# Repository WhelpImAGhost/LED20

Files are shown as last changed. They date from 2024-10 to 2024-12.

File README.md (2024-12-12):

# ECE 411 - LED20
### Team 1
- Brad Glaubitz
- Chris Kane-Pardy
- Caleb Monti
- Henry Sanders

## Project Overview
The purpose of the LED20 project is to add a fun and interesting spin to modern D20s (20 sided dice) for various tabletop games. Rather than a standard D20 which simply shows which face is rolled, the LED20 will illuminate the face that was rolled, and play special sound effects when a 1 or 20 is rolled. This added flare will spice up any tabletop game, and can be customized to your liking! [^1]

## Important Files and Folders Directory
This repository holds all design and development documents that were either assigned or created out of necessity throughout this project, including the Product Design Specification and Bill of Materials. However, for someone interested in creating their own copy of the LED20, some of these files and folders are not required. So, we have compiled a list of the files and folders that are necessary for understanding and replicating this project

### Links to files and folders
- [Full Project Description](./Project%20Info%20and%20Requirements/Project%20Information%20and%20Requirements.pdf): A more in-depth explanation of the project details and required features
- [Functional Decomposition](./Functional%20Decomposition/): Other high-detail files which explain the inner hardware and software functions and connections
- [Bill of Materials](./BOMs/Bill%20of%20Materials%20v4.xlsx): The list of required components to recreate the circuit
- [3D Model Files](./CAD/3D%20Model/): Iterations of development for the 3D printed D20 enclosure and charging base
- [PCB Development Files](./CAD/Schematics%20and%20PCB%20Layouts/): Required files for modifying or fabricating the carrier circuit board
- [Code](./LED20_Code/): Most recent iteration of the code, developed using ESP-IDF for the ESP32-C6

[^1]: Customization must take place before the die is sealed, as there is not a current way to interface with the processor after the enclosure is fully sealed. Please make any changes to LED Color, 1 & 20 Tones, and Sleep States before sealing your die.

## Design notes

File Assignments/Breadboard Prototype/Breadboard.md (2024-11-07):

# Breadboard Prototype Update

Our breadboard prototype is coming along nicely. All features that we currently have in hand are functional and controllable, including:

- Controlling the ESP32-C6
- Configuring, writing to, and reading from the LSM6D032 Accelerometer and Gyroscope sensor
- Enabling and controlling interrupts from the LSM6D032 sensor
- Controlling a fixed number of NeoPixel or WS2811 LEDs with fixed timing

Below is a close-up image of our current breadboard prototype
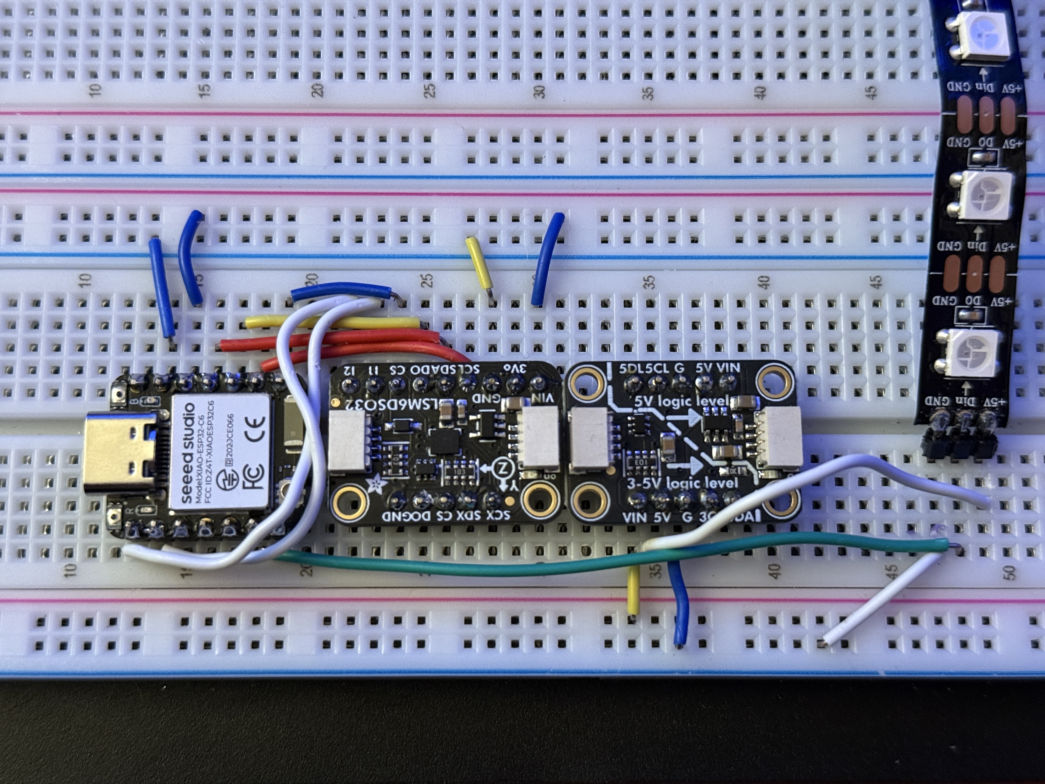
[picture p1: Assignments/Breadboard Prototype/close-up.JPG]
Breadboard Prototype close-up


We also have a couple images representing our data transfers between the ESP32-C6 and the LSM6D032 sensor over a 4-wire SPI interface:

Example SPI transfer using a logic analyzer:
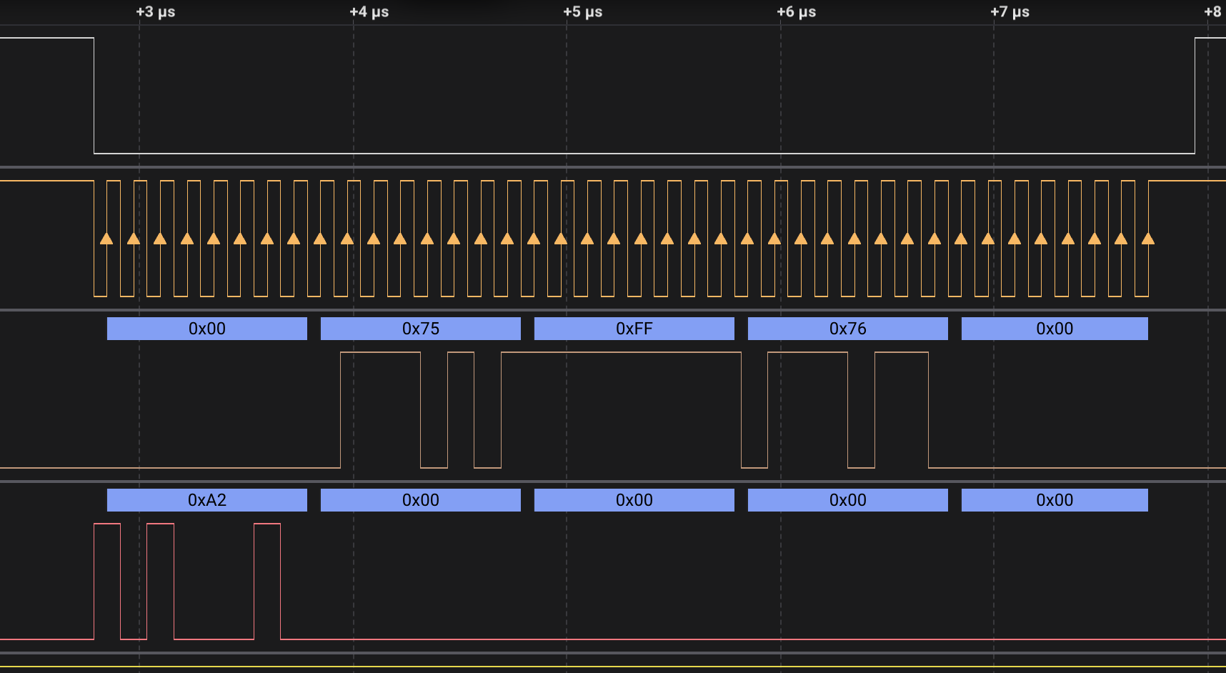
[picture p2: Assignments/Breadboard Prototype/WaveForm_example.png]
Logic analyzer example


In this image, you can clearly see the interaction and data that was transferred between the two devices. In this case, the ESP32-C6 was reading from four registers starting at register 0xA2 and receiving four data packets from the LSM6D032.

Next, an image showing our data after some computation into a human-readable format:  
Example data in human-readable format  
In this image, the hex data from the LSM6D032 is converted to a physical number we can use to determine information such as when the die stops moving and what orientation it is in when it stops moving.

Finally, the lightshow!
[Click here for lightshow video](https://youtu.be/P9tXDaBaYNc), or alternatively see the "animated-lights.mov" file.

With all of our code functioning individually, we are very close to having a fully functional project on the code side.

### Note
One of our project requirements is to make sound when a certain roll is detected. Currently the Piezo to do such sounds is not installed on the ESP32-C6, but creating a PWM signal from the ESP32-C6 to drive a passive buzzer is beyond trivial. The main focus on the code to this point has been to develop the more complex and intricate code and components to get them to function in unison.

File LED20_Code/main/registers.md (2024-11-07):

# Registers and values required

### Notes on sensor setup
- Disable I2C in CTRL4_C
- Set Accelerometer operation mode in register CTRL1_XL (0x10)
- Set Gyroscope operation mode in register CTRL2_G (0x11)
- Software Reset, Register Increment, and interrupt activation level set in CTRL3_C (0x12)
- Disable I3C using CTRL9_XL

### Notes on Interrrupt setup
- Interrupt Setup is configured by switching to Embedded Function control mode by writing 0x1 to the FUNC_CFG_ACCESS (0x1) register
- Enable "Significant Motion Detection" in register EMB_FUNC_EN_A (04h)
- Route SMD interrupt to INT1 and Inactivity to INT2

- Interrupt status cleared by reading interrupt register
    - For SMD interrupt, read EMB_FUNC_STATUS_MAINPAGE (0x35) register
- TAP has inactivity sensor. Activity interrupt can be used to wake processor from sleep

### Notes on Data Acquisition
- Data is back into two bytes, stored in Two's Complement format
- L register is bits 7-0, H register is 15-8
- Accelerometer data registers:
    - OUTX_L_A (0x28) and OUTX_H_A (0x29) - X axis linear acceleration
    - OUTY_L_A (0x2A) and OUTY_H_A (0x2B) - Y axis linear acceleration
    - OUTZ_L_A (0x2C) and OUTZ_H_A (0x2D) - Z axis linear acceleration
- Gyroscope data registers:
    - OUTX_L_G (0x22) and OUTX_H_G (0x23) - X axis angular rate value
    - OUTY_L_G (0x24) and OUTY_H_G (0x25) - Y axis angular rate value
    - OUTZ_L_G (0x26) and OUTZ_H_G (0x27) - Z axis angular rate value
- Temperature data registers:
    - OUT_TEMP_LOW (0x20) and OUT_TEMP_HIGH (0x21) - Temperature output register

# Cheatsheet

# A first-level heading
## A second-level heading
### A third-level heading

Style	Syntax	Keyboard shortcut	Example	Output
Bold	** ** or __ __	Command+B (Mac) or Ctrl+B (Windows/Linux)	**This is bold text**	This is bold text
Italic	* * or _ _     	Command+I (Mac) or Ctrl+I (Windows/Linux)	_This text is italicized_	This text is italicized
Strikethrough	~~ ~~	None	~~This was mistaken text~~	This was mistaken text
Bold and nested italic	** ** and _ _	None	**This text is _extremely_ important**	This text is extremely important
All bold and italic	*** ***	None	***All this text is important***	All this text is important
Subscript	<sub> </sub>	None	This is a <sub>subscript</sub> text	This is a subscript text
Superscript	<sup> </sup>	None	This is a <sup>superscript</sup> text	This is a superscript text
Underline	<ins> </ins>	None	This is an <ins>underlined</ins> text	This text is underlined

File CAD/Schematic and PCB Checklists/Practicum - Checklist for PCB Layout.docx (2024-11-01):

# Checklist for PCB Layouts

Andrew Greenberg - http://github.com/andrewgreenberg

v2021-10-28

Pre-layout Checklist

- Create board from schematic.
- Set your grid to something reasonable (e.g., 0.1 mm grid, or 0.01 inch grid).
- Start with your best guess for an outline of your board.

Lay out strategies

- Place all components that must be in a certain spot (e.g., connectors and mounting holes)
- Move components that are in a “schematic block” together, then optimally rotate and place components to reduce crossed airwires, then route.
- Optimally rotate and place grouped components to minimize airwires, then route.
- Flood ground planes, stitching them together early and often.
- Route very high speed lines (e.g., RF, clocks, USB 2.0), minimizing length
- Route power lines, minimizing impedance.
- Route busses.
- Route everything else.

Layout checklist

- Is there enough physical space around components for assembly?
- Are your test points in easily accessible places?
- Are there any hidden traces that you can't probe?

Best Practices

- Are all of the small bypass caps right next to the power and ground leads of the ICs?
- Are the power lines as wide as reasonably possible?
- Did you use either larger drills for power lines, or multiple small vias for power lines?
- Are there ground planes on both sides? (Make sure your polygons have an isolate of > design rule; e.g., with a design rule of 6 mils, make the isolate 10 mils).
- Are your ground planes stitched together with vias?
- Is your board as small as possible?
- Run your DRC early and often

Post-layout checklist

- Modify reference designators to be as small as possible, and move them around to be readable/useful. Avoid placing text on pads and vias.
- Verify that at least the organization name, the name of the board, and version number are on the silkscreen.

Final checkout

- Print out 1:1 PCB and lay components on printout to double check packages.
- Run DRC; there should be no errors.
- Make sure all components in stock, or that components you specified are in stock before firing off board.

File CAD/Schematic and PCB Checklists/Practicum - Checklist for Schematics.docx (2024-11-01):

# Checklist for Schematics

Andrew Greenberg - http://github.com/andrewgreenberg

v2021-10-29

- Visual Design
  - Power supplies use supply symbols, not wires
  - Positive supplies point up, and negative supplies/ground point down
  - Optional: Groups of nets above about ≥ 4 nets collected into buses
  - Component symbols are symbols, not the physical package's order and arrangement
  - All nets descriptively named
  - Net “stubs” (nets visually connected to only one pin) use an “off-sheet” type of label
  - Blocks in your schematic clearly labeled
  - There's a frame around the schematic
  - It's clear where your power is coming from
  - It's clear what your power input requirements are
  - Data flow (inputs, outputs) are clear and labeled
- Part values
  - Special case capacitors marked with power and tolerance
  - Capacitors have the appropriate voltage
  - Power dissipation checked in all of your resistors
  - Special case resistors marked with power and tolerance
  - Check that your specialized parts are in stock at a distributor
- Electrical Rule checks
  - All of your components have values (including “NP” for "No Place")
  - All inputs have the correct voltage levels
  - All outputs have the correct load impedance
  - MOSFETs oriented correctly, including the body diode
  - No unapproved errors OR warnings in the ERC
  - Double check your approved errors, looking for anomalies and possible errors.
- Best Practices
  - Your schematic is peer reviewed by at least one person not involved in the design.
  - Small, low ESR (e.g., ceramic) bypass capacitors on ALL IC supplies
  - Large bypass (e.g., electrolytic) capacitors on your board at the power connector and regulator IC.
  - Design for Test
    - Place test points on critical signals
    - Add debugging hardware (e.g., test switches, LEDs, scope probe points, etc)
  - Design for Fail
    - Group components in separable modular blocks, use zero ohm resistors as jumpers
  - Design for Manufacturing
    - Place programming connectors and DOUBLE CHECK their pinouts
    - Double check your part numbers and the actual package names and dimensions.

Please comment (https://docs.google.com/document/d/1tzhaX46BbXsmi481ztf1Z_laDdik5dUJDNGWxPAsZL4/edit?usp=sharing) on this checklist!

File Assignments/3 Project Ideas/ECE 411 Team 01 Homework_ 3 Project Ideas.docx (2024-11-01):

ECE 411 Homework: 3 Project Ideas

Idea 1: ASL Glove (cont. from ECE 212)

- Brief description: Device that translates ASL to English or other languages in real time to text and/or speech. Optimized for better processing and speed
- List of sensors: Gyroscope, Accelerometer, Resistive flex sensor
- List of controllers: ESP32 or Arduino Nano
- List of actuators: Phone App

Idea 2: Tile Rhythm Game

- Brief description: Similar to BopIt™, but a tiled “drum pad” with X number of pads that light up and play a sound in a particular order which the user then has to repeat back.
- List of sensors: Capacitive or Piezo force sensors
- List of controllers: ESP32, RPi Pico, or Arduino Nano
- List of actuators: LEDs, sound

Idea 3: LED20

- Brief description: D20 that lights up the rolled number, may play sound upon rolling a 1 or 20. May detonate upon rolling 2 consecutive 1s
- List of sensors: Gyroscope, Accelerometer,
- List of controllers: ESP32-S3 or RP2040
- List of actuators: LEDs, sound

Why we chose LED20: The idea seems reasonable to achieve within the timeframe of the class. Additionally, it checks all the project requirement boxes.

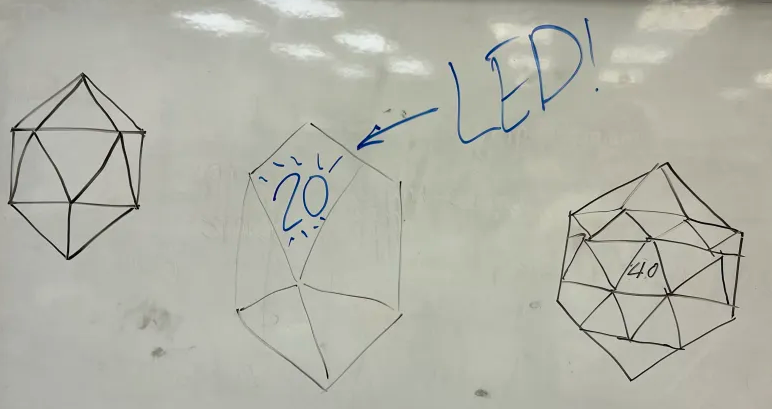
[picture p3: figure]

Caleb Monti Brad Glaubitz Henry Sanders Chris Kane-Pardy 10 October 2024

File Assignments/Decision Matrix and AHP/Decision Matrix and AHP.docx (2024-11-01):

Practicum Team 01: Decision Matrix and Analytical Hierarchy Process (AHP)

For the decision matrix and analytical hierarchy process, we opted to decide on which battery to use for our LED20 project. There were three candidates: the LP401230, LP503035, and CR2032. The criteria we decided to base this decision on are voltage, capacity, cost, size, weight, life, and rechargeability.

Below is the LED20 Battery Decision Matrix. The weights and ratings relative to the criteria were decided via group consensus. The only calculations necessary for the decision matrix are in the “Score” row. The number you see is the summation of the weight multiplied by the rating for that criterion in the column above it.

LED20 Battery Decision Matrix
Criteria | Weight | LP401230 | LP503035 | CR2032
Voltage | 4 | 4 | 4 | 2
Capacity | 4 | 1 | 5 | 2
Cost | 2 | 3 | 1 | 5
Size | 5 | 4 | 1 | 5
Weight | 1 | 5 | 2 | 5
Life | 3 | 1 | 5 | 2
Rechargeability | 5 | 5 | 5 | 1
Score | | 79 | 85 | 67

(Table 1: LED20 Battery Decision Matrix)

From the matrix above, we can see that the LP503035 LiPo battery came out victorious.

Next, we began running calculations for the AHP. First, we determined the criteria weightings using the table below. To do this, we first decided on how to weigh each criterion relative to the other criteria. We then took the geometric mean of each row which is represented in the “Mean” column. The “Weight” column is then the geometric mean for that row divided by the total mean. By doing this, we obtained our criteria weights to be used in the AHP.

Criteria | Voltage | Capacity | Cost | Size | Weight | Life | Rechargeability | Mean | Weight
Voltage | 1.00 | 0.33 | 1.00 | 0.25 | 1.00 | 0.50 | 0.33 | 0.54 | 0.07
Capacity | 3.00 | 1.00 | 3.00 | 0.25 | 5.00 | 1.00 | 4.00 | 1.72 | 0.21
Cost | 1.00 | 0.33 | 1.00 | 1.00 | 1.00 | 3.00 | 0.25 | 0.82 | 0.10
Size | 4.00 | 4.00 | 1.00 | 1.00 | 4.00 | 1.00 | 2.00 | 2.00 | 0.25
Weight | 1.00 | 0.20 | 1.00 | 0.25 | 1.00 | 3.00 | 0.33 | 0.65 | 0.08
Life | 2.00 | 1.00 | 3.00 | 1.00 | 0.33 | 1.00 | 0.50 | 1.00 | 0.12
Rechargeability | 3.00 | 0.25 | 4.00 | 0.50 | 3.00 | 2.00 | 1.00 | 1.37 | 0.17
| | | | | | | Total | 8.10 | 1.00

(Table 2: Criteria Table)

We then created another table to determine alternative ratings relative to our criteria. These values would be used as a basis for our normalization calculations. The table below simply contains the values of each criterion in their respective units i.e. voltage [V], cost [$], etc.

Alternative Ratings Relative to Criteria
Batteries | LP401230 | LP503035 | CR2032 | Total
Voltage | 3.70 | 3.70 | 3.00 | 10.40
Capacity | 100.00 | 500.00 | 210.00 | 810.00
Cost | 5.95 | 7.95 | 2.10 | 16.00
Size | 1354.70 | 4959.00 | 1005.31 | 7319.01
Weight | 3.00 | 10.50 | 3.10 | 16.60
Life | 2.00 | 10.00 | 4.20 | 16.20
Rechargeability | 1.00 | 1.00 | 0.00 | 2.00

(Table 3: Alternative Ratings Relative to Criteria)

For the “Normalization” table, we performed the normalization based on either the maximum or minimum value in that category. For voltage, a higher value is preferred, so the formula becomes the criterion divided by the maximum value among the criteria. For size, a smaller value is preferable, so the formula becomes the minimum of the criteria divided by the criterion. The outlier to this formula is the rechargeability criterion, which was based on the battery either being rechargeable or not. If so, the battery was given a value of one, and if not it was given a zero.

Normalization | LP401230 | LP503035 | CR2032 | Total
Voltage | 1.00 | 1.00 | 0.81 | 2.81
Capacity | 0.20 | 1.00 | 0.42 | 1.62
Cost | 0.35 | 0.26 | 1.00 | 1.62
Size | 0.74 | 0.20 | 1.00 | 1.94
Weight | 1.00 | 0.29 | 0.97 | 2.25
Life | 0.20 | 1.00 | 0.42 | 1.62
Rechargeability | 1.00 | 1.00 | 0.00 | 2.00

(Table 4: Normalization Table)

The full AHP table is below. The weight column is pulled directly from the weight column in the Criteria Table (2). The individual criterion values are then the ratio of the normalized value and the total normalized value. Similar to the “Score” row in the LED20 Battery Decision Matrix (1), the “Score” row in the table below is the summation of the weight multiplied by the normalized value for each criterion in the column above the score value.

LED20 Battery Analytical Hierarchy Process (AHP)
Criteria | Weight | LP401230 | LP503035 | CR2032 (LMO Coin Cell)
Voltage | 0.07 | 0.36 | 0.36 | 0.29
Capacity | 0.21 | 0.12 | 0.62 | 0.26
Cost | 0.10 | 0.22 | 0.16 | 0.62
Size | 0.25 | 0.38 | 0.10 | 0.51
Weight | 0.08 | 0.44 | 0.13 | 0.43
Life | 0.12 | 0.12 | 0.62 | 0.26
Rechargeability | 0.17 | 0.50 | 0.50 | 0.00
Score | | 0.30 | 0.37 | 0.33

(Table 5: LED20 Battery AHP)

The AHP agrees with our original decision matrix and shows that all three batteries would work for our project, with the positives and negatives being nearly equal. However, because we weighted particular criteria more heavily than others (capacity > cost, for example), the LP503035 was ultimately the best choice for our project.

Caleb Monti Brad Glaubitz Henry Sanders Chris Kane-Pardy 28 October 2024

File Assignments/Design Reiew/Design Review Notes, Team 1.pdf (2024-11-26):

Caleb Monti
Brad Glaubitz
Henry Sanders
Chris Kane-Pardy
21 November 2024

## Design Review: Team 01

### Note to self:

Schedule DR with Nic for 6-6:30 tomorrow DR with Nathan’s team tomorrow at 7:30

### General Notes:

Brad was 2 minutes late to Team 04’s DR 😠 Brad’s doing a really good job 🥰🥰

### Team 04 DR:

### Schematic:

- Where are the contact points?
- The contact points will be on the outside face of the die.
- Have we considered a weighted/rigged die?
- It will most likely be loaded since we haven’t been prioritizing weight. We are thinking of ideas currently for how to weight it properly, maybe with steel bearings.
- Have we considered just having a dense center of mass?
- No, not really.
- What bus is going between the microcontroller and the gyroscope?
- 4-wire SPI because the 3-wire SPI was harder to implement.
- Is the IC for the Accelerometer/Gyro one or two ICs?
- One IC.
- Are we planning on playing tunes through a regular Piezo speaker?
- Yeah, it’ll most likely be kinda 8-bit, like a sequence of notes or something, nothing too crazy. We have to consider power usage here as well.
- What’s with the PWM on the Piezo input signal?
- No volume control, using an analog pin to vary it, and if that doesn’t work we’ll use a digital PWM.
- Is the plan for the Piezo speaker to have a summary volume - no user setting?
- No plan currently for user settings.
- Will the enclosure be set or is it openable by the user?
- The enclosure will be press-fit. We’re hoping the 3D housing muffles the volume of the speaker somewhat since they are typically pretty loud. We haven’t fully experimented with it yet.

- Do we have any plans for shock absorption for protecting soldering junctions and the PCB itself?
- We don’t have solder joints for the battery or LED needs, we’re using JST connectors that lock together. So for the most part those wires shouldn’t come loose or be impacted. The PCB will be attached in such a way that it won’t move around freely within the enclosure. We’ll be testing this rigorously when we have a PCB to put into the enclosure.

### PCB:

- Acid traps a concern warranting a potential change.
- If we make changes for acid traps, will we have issues with overlap?
- No, not really, it shouldn’t be an issue.
- To keep it small enough so that we didn’t have to build the world’s largest LED20, were you forced to use the back side of the PCB?
- Yes, that’s correct. We were slightly concerned with the thickness or height of our board when making this decision, but we measured everything out and it should be good to go.
- Are we doing a refill on the backside for our microcontroller?
- Yes, as much as we can get away with it.
- Since we’re on an SPI bus, are we going to try and set it up so we increase the size of the packet when doing a temperature reading?
- Yes.
- Is it an option to concatenate blank temp data so we can keep the size the same without having to write to our config registers, or is that not something worth looking into?
- We can queue transactions and then do a bunch at once, and toggle whether or not to do a temperature transaction. It can do all transactions at once, or 4 or 5 at a time, and report back data all at once, and then we can parse it.
- Was the gyroscope/accelerometer set to be off-center on purpose?
- It doesn’t matter where it is. We were just trying to make everything fit since we’re so space-constrained. We could probably put it in the center, but it’s not an issue at the moment.
- As far as battery consumption goes, what are we doing to lower the power consumption of the microprocessor?
- Everything is interrupt-driven, our two states are active and inactive. After enough time being active, it will switch to inactive. Int1 and Int2, SMD on Int1, Int2 for wake/sleep. However, SMD is for steps/counter so it’s not beneficial. Currently, Int2 is sending a logic high when it is inactive, and a logic low when it is active.
- Is there anything we can do to stop it from going into active mode when it's in someone’s backpack or car or something?
- The way we get around that is to set the threshold high enough so that smaller motion doesn’t switch it into active mode. The other option is creating a deep-sleep state, only able to be triggered out of with a much higher threshold. We currently don’t have a way to turn it off when it's enclosed in the die. Looking into deep-sleep state options. Ideally, we could have a power switch, but it's hard to do without interfering with the face of the die.

### Extra:

Brad: Do you have any thoughts on additions?
Nathan: My big thing is it seems like we knew we were gonna skew the probabilities of the die which it seems like you kinda hand-waved a bit.
Brad: We’ll try to resolve it.
Nathan: Stock bullshit answer. Probabilistic modeling, doing a bunch of testing, etc. Wireless charging would be cool too.
Brad: In general, it’s inefficient. There’s also a size restriction issue with wireless charging we were concerned about getting right.
Chris: Greenburg is also concerned about radiation.

### Nic Redfield DR:

- Widen traces to at least 12 mil (0.305mm) We've got lots of extra ground beneath the accel/gyro to play with, he also suggested adding a via in the middle of the accel/gyro and routing pin 13 to it, taking it to the front and finishing the route that way. This will allow for more room to widen our traces since they're currently crowded around that area.
- The aperture size for the silk screen is okay based on OSH Park's request

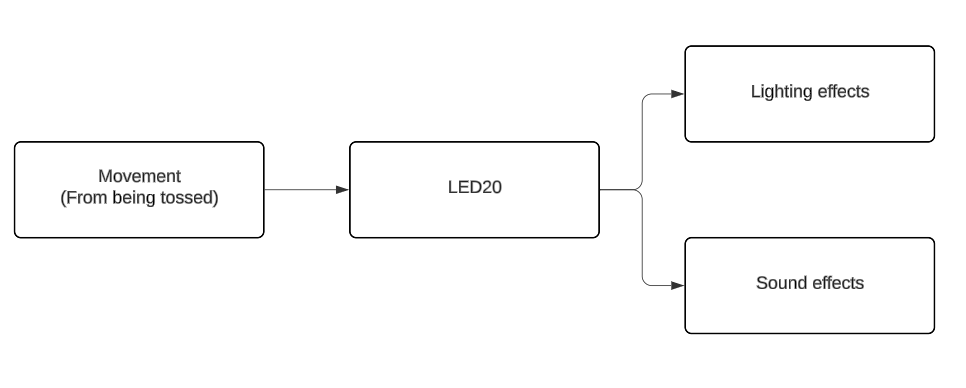
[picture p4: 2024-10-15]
PDS/Block Diagrams/L0 Block Diagram.png

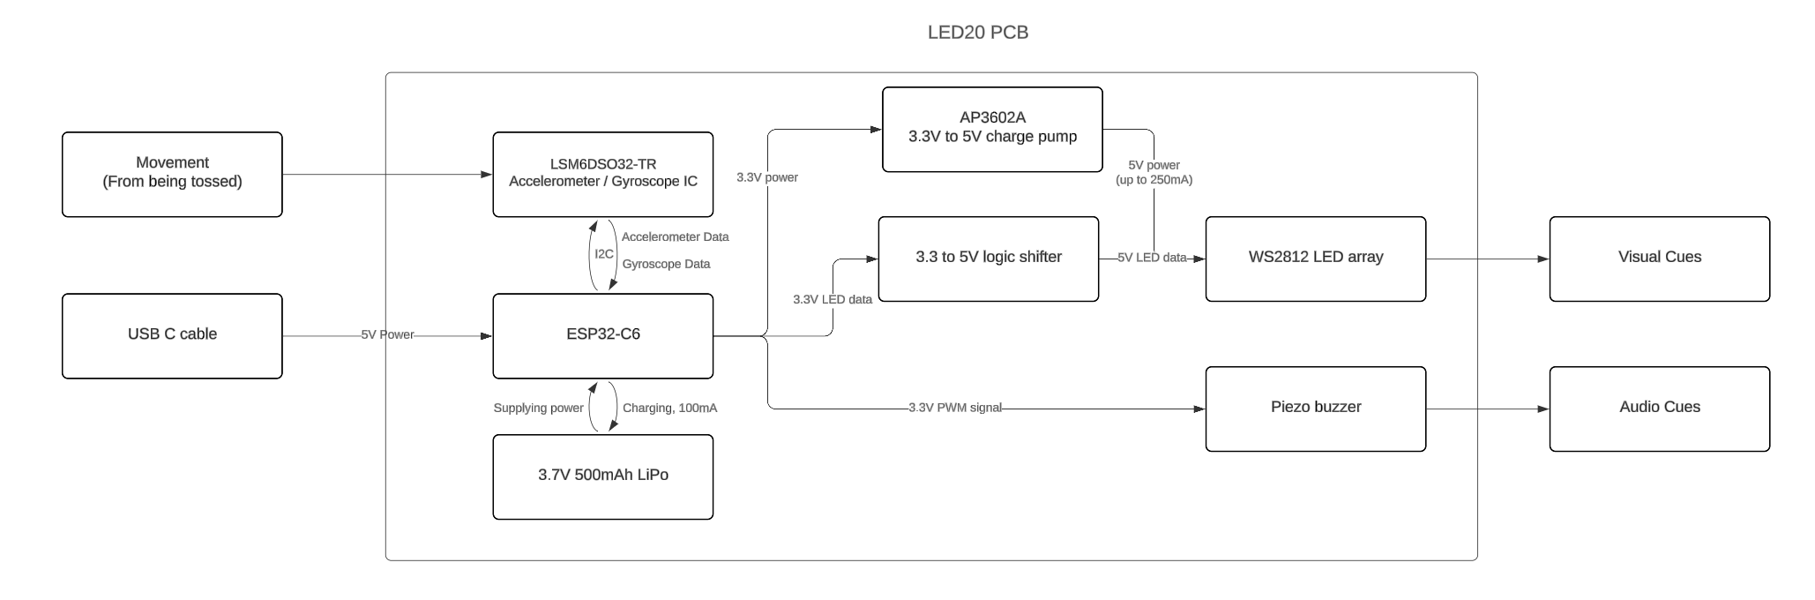
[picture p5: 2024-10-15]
PDS/Block Diagrams/L1 Block Diagram.png

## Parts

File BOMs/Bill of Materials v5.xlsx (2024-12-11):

Last modified: 2024-12-10
PCB version: 5.6
BOM revision: 5 |  | P/NP | = Place/Not Place (components marked NP are not stuffed on the board)
Cnt | Part References | P/NP | Mfg | Mfg PN | Description | Dist | Dist Part Number | Cost Ea. | Cost Total
100 | D1 - D20 | P | OPSCO OPTOELECTRONICS | SK6812MINI-B-00 | NeoPixel Mini 3535 RGB LEDs w/ Integrated Driver Chip | Adafruit | 4957 | $0.20 | $19.95
4 | U4 | P | Seeed Studio | 113991254 | Seeed Studio XIAO ESP32C6 Microcontroller | Seeed Studio | 8543708800 | $5.20 | $20.80
2 | Protoboard Only | NP | Adafruit | 5649 | QT 3V to 5V Level Booster Breakout Board | Adafruit | 5649 | $2.95 | $5.90
4 | No Ref Des | P | Shenzhen PKCELL Battery Co. | LP-523334 | 3.7V 500mAh LiPo Battery | Adafruit | 1578 | $7.95 | $31.80
2 | Protoboard Only | NP | STMicroelectronics | LSM6DSO32 | 6-DoF Accelerometer and Gyroscope | Adafruit | 4692 | $12.50 | $25.00
10 | U2 | P | Diodes Incorporated | AP3602AKTR-G1 | 3.3V DC to 5V DC Step-Up (Boost) Output Regulator (100mA) | DigiKey | 31-AP3602AKTR-G1CT-ND | $0.48 | $4.81
6 | U1 | P | STMicroelectronics | LSM6DSO32TR | Accelerometer, Gyroscope, 6 Axis Sensor, I2C/SPI | DigiKey | 497-LSM6DSO32CT-ND | $4.09 | $24.56
24 | C2,C3 | P | Samsung Electro-Mechanics | CL10A106KQ8NNNC | 10μF ± 10%, Ceramic Capacitor 0603, 6.3V | DigiKey | 1276-1038-1-ND | $0.07 | $1.61
12 | C1 | P | Samsung Electro-Mechanics | CL10B105KP8NNNC | 1μF ± 10%, Ceramic Capacitor 0603, 10V | DigiKey | 1276-1946-1-ND | $0.03 | $0.38
20 | C4,C5 | P | Samsung Electro-Mechanics | CL10B104KB8NNNC | 100nF ± 10%, Ceramic Capacitor 0603, 50V | DigiKey | 1276-1000-1-ND | $0.03 | $0.50
10 | U7,U6 | P | JST Sales America Inc | B2B-PH-K-S | Connector Header, Through Hole, 2-Position | DigiKey | 455-1704-ND | $0.13 | $1.28
10 | U6 | P | Same Sky | CPG-04-N-B | PC Pin Terminal Connector, Through Hole, Gold, ~1mm D | DigiKey | 2223-CPG-04-N-B-ND | $0.69 | $6.86
10 | U7 | P | Same Sky | CPG-05-N-B | Contact Point, 1.55mm Head | DigiKey | 2223-CPG-05-N-B-ND | $0.36 | $3.58
6 | LS1 | P | Same Sky | CMT-7525-80-SMT-TR | Externally Driven, 3.6V, 100mA, SMD Buzzer Transducer | DigiKey | 102-CMT-7525-80-SMT-CT-ND | $1.28 | $7.68
10 | D1 | P | Adam Tech | 2SH-C-03-TS | CONN HEADER VERT 3POS 2MM | DigiKey | 2057-2SH-C-03-TS-ND | $0.10 | $1.01
12 | No Ref Des | P | JST Sales America Inc | 02KR-D6S-P | 2 Position Rectangular Socket Connector IDC Tin 26 AWG | DigiKey | 455-2701-ND | $0.37 | $4.42
8 | No Ref Des | P | JST Sales America Inc | 03KR-D6S-P | 3 Position Rectangular Socket Connector IDC Tin 26 AWG | DigiKey | 455-2700-ND | $0.42 | $3.40
4 | CR1 | P | onsemi | S1B | DIODE GEN PURP 100V 1A DO214AC | Digikey | S1BFSCT-ND | $0.35 | $1.40
4 | U3 | P | onsemi | MMBT4401L | TRANS NPN 40V 0.6A SOT23-3 | Digikey | MMBT4401LT1GOSCT-ND | $0.14 | $0.56
4 | R1 | P | Panasonic Electronic Components | P.18AJCT-ND | RES 0.18 OHM 1% 1/10W 0603 | Digikey | ERJ-3RSFR18V | $0.23 | $0.92
 |  |  |  |  |  |  |  | TOTAL: | $166.42
VERSION INFO
Rev | Date | Notes
v1.0 | 2024-11-14 | First Draft of Inclusive BOM
v2.0 | 2024-11-14 | Added Connectors
v3.0 | 2024-11-14 | Changed QTY of BZ1 to 6 and U2 to 10 and JST 3 hole connector to QTY 10
v4.0 | 2024-11-29 | Final Variant
v5.0 | 2024-12-10 | Added BJT and Diode

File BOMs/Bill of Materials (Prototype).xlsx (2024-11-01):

 |  | Charge IC not needed, uC has one embedded
 | Item | Link | Price Per Each | Quantity | Total Cost
x | Neopixels | NeoPixel Mini (https://www.adafruit.com/product/4957) | 0.1995 | 100 | 19.95
x | ESP32 | Tiny Matter-Native Board (https://www.seeedstudio.com/Seeed-Studio-XIAO-ESP32C6-p-5884.html) | 5.2 | 4 | 20.8 | 28.75
x | Accelerometer Breakout | Adafruit LSM6DSO32 6-DoF Accelerometer and Gyroscope (https://www.adafruit.com/product/4692) | 12.5 | 2 | 25 | 2.90
x | 500mAh LiPo Battery | https://www.adafruit.com/product/1578 | 7.95 | 4 | 31.8
x | Boost + level shifter | https://www.adafruit.com/product/5649 | 2.95 | 2 | 5.9

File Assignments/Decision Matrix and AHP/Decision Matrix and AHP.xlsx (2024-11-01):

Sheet: DM and AHP
LED20 Battery Decision Matrix |  |  |  |  | Criteria | Voltage | Capacity | Cost | Size | Weight | Life | Rechargeability | Mean | Weight
Criteria | Weight | LP401230 | LP503035 | CR2032 (LMO Coin Cell) | Voltage | 1.00 | 0.33 | 1.00 | 0.25 | 1.00 | 0.50 | 0.33 | 0.54 | 0.07
Voltage | 4 | 4 | 4 | 2 | Capacity | 3.00 | 1.00 | 3.00 | 0.25 | 5.00 | 1.00 | 4.00 | 1.72 | 0.21
Capacity | 4 | 1 | 5 | 2 | Cost | 1.00 | 0.33 | 1.00 | 1.00 | 1.00 | 3.00 | 0.25 | 0.82 | 0.10
Cost | 2 | 3 | 1 | 5 | Size | 4.00 | 4.00 | 1.00 | 1.00 | 4.00 | 1.00 | 2.00 | 2.00 | 0.25
Size | 5 | 4 | 1 | 5 | Weight | 1.00 | 0.20 | 1.00 | 0.25 | 1.00 | 3.00 | 0.33 | 0.65 | 0.08
Weight | 1 | 5 | 2 | 5 | Life | 2.00 | 1.00 | 3.00 | 1.00 | 0.33 | 1.00 | 0.50 | 1.00 | 0.12
Life | 3 | 1 | 5 | 2 | Rechargeability | 3.00 | 0.25 | 4.00 | 0.50 | 3.00 | 2.00 | 1.00 | 1.37 | 0.17
Rechargeability | 5 | 5 | 5 | 1 |  |  |  |  |  |  |  | Total | 8.10 | 1.00
Score |  | 79 | 85 | 67
LED20 Battery Analytical Hierarchy Process (AHP)
Criteria | Weight | LP401230 | LP503035 | CR2032 (LMO Coin Cell)
Voltage | 0.07 | 0.36 | 0.36 | 0.29
Capacity | 0.21 | 0.12 | 0.62 | 0.26
Cost | 0.10 | 0.22 | 0.16 | 0.62
Size | 0.25 | 0.38 | 0.10 | 0.51
Weight | 0.08 | 0.44 | 0.13 | 0.43
Life | 0.12 | 0.12 | 0.62 | 0.26
Rechargeability | 0.17 | 0.50 | 0.50 | 0.00
Score |  | 0.30 | 0.37 | 0.33
Batteries | LP401230 (LiPo) | LP503035 (LiPo) | CR2032 (LMO Coin Cell)
Voltage | (3.0,3.7,4.2)V | (3.0,3.7,4.2)V | (x,3,x)V
Capacity | 100mAh | 500mAh | 210mAh
Cost | $5.95 | $7.95 | $2.10
Size | (11.5 x 31 x 3.8)mm | (29 x 36 x 4.75)mm | (20 x 3.2)mm
Weight | 3g | 10.5g | 3.1g
Life | 2h | 10h | 4.2h
Rechargeability | yes (1) | yes (1) | no (0)
Alternative Ratings Relative to Criteria
Batteries | LP401230 (LiPo) | LP503035 (LiPo) | CR2032 (LMO Coin Cell) | Total
Voltage | 3.70 | 3.70 | 3.00 | 10.40
Capacity | 100.00 | 500.00 | 210.00 | 810.00
Cost | 5.95 | 7.95 | 2.10 | 16.00
Size | 1354.70 | 4959.00 | 1005.31 | 7319.01
Weight | 3.00 | 10.50 | 3.10 | 16.60
Life | 2.00 | 10.00 | 4.20 | 16.20
Rechargeability | 1.00 | 1.00 | 0.00 | 2.00
Normalization | LP401230 (LiPo) | LP503035 (LiPo) | CR2032 (LMO Coin Cell) | Total
Voltage | 1.00 | 1.00 | 0.81 | 2.81
Capacity | 0.20 | 1.00 | 0.42 | 1.62
Cost | 0.35 | 0.26 | 1.00 | 1.62
Size | 0.74 | 0.20 | 1.00 | 1.94
Weight | 1.00 | 0.29 | 0.97 | 2.25
Life | 0.20 | 1.00 | 0.42 | 1.62
Rechargeability | 1.00 | 1.00 | 0.00 | 2.00

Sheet: Battery Information
Batteries | LP401230 (LiPo) | LP503035 (LiPo) | CR2032 (LMO Coin Cell)
Voltage | (3.0,3.7,4.2)V | (3.0,3.7,4.2)V | (x,3,x)V
Capacity | 100mAh | 500mAh | 210mAh
Cost | $5.95 | $7.95 | $2.10
Size | (11.5 x 31 x 3.8)mm | (29 x 36 x 4.75)mm | (20 x 3.2)mm
Weight | 3g | 10.5g | 3.1g
Life | depends on i | depends on i | depends on i
Rechargeability | yes | yes | no

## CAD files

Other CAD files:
CAD/3D Model/LED20 Testing Pegs v3.f3d
CAD/3D Model/LED20 no Cuts v2.f3d

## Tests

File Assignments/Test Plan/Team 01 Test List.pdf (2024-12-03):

Caleb Monti
Brad Glaubitz
Henry Sanders
Chris Kane-Pardy
25 November 2024
Team 01: Test Plan List
- Unit tests
- Charging contacts
■ Test 5V supplied from charging contacts
- Microcontroller
■ Test 5V received from charging contacts
■ Test 3.7V received from battery
■ Interrupt signal actives are logic-low (0V) and inactive are logic-high (3V)
■ Read fixed value from register to determine communication between sensor and ESP32-C6 is working
- Sequence for testing communication between ESP32-C6 and LSM6D032:
- Test SPI communication (WHOAMI register)
- Test LSM6D032 register setup (read all config registers that were written to)
- Test LED GPIO setup (initialize without error)
- Test LED communication (Send LED RGB strobe, then off)
- Test reading LSM6D032 data values (should return various hex values)
- Test ESP32 interrupt initialization (initialize with no error)
- Test dummy interrupt on ESP32 (use the jumper, it should print ACKs)
- Test LSM6D032 interrupt initialization (should trigger ACKs from the previous step)
- Test repeated interrupt triggering (Activity/Inactivity, Data Ready)
- Test data parsing (no data values should be exactly 0, value should be within tolerance for that side)
- Test data interpretation (given hard-coded value, should pick coded face)
- Test interrupt triggering from rolls (rolling should start the sequence)
- Test interrupt threshold from table bumps or slight movement ( threshold should be high enough to ignore these)

- Test repeated triggering of interrupts from rolls (should go multiple times with no issue)
- Test sleep state after inactivity
- Accelerometer/Gyroscope
■ Ensure SMD is returning values
■ Output testing is done with ESP32-C6
- Battery
■ Test charging current (expected value: ≤ 100mA) ■ Test 3.7V output to microcontroller
- Charge Pump
■ Test 3.3V input from microcontroller
■ Test 5V output to LED array
- Buzzer
■ Test 3.3V PWM input from microcontroller ■ Test audio outputs operating correctly
- LED Array
■ For all LEDs in the array
- Test 5V power input from the charge pump
- Test 3.3V data input from the microcontroller
- Ensure each LED turns on and off
- Verification tests
- Test buzzer operational on critical rolls (die lands on 1 and/or 20)
- Test correct LED is on (face of die in (0,0,z)) after roll of die
■ Ensure no other LEDs are lit other than the face of the die in (0,0,z)
- Test LED turns off after a set amount of time
- Test sleep timers
■ Ensure power consumption is limited in sleep mode
- Test variety of 3D printer filaments for enclosure (for structural integrity -both on the seam of the two halves, the pegs, peg holes, internal PCB enclosure, and outermost edges, vertices, and faces)
■ Ambrosia Galactic PLA
■ Ambrosia PLA
■ MatterHackers Translucent PETG
■ Prusa Research Prusament PLA ■ Sunlu PLA+
■ Resin
- Validation tests
- Musts:
■ Ensure the user’s rolled number is illuminated on the upright (0,0,z) face of the die

■ Test battery life lasts 4-6 hours
■ Test ability to withstand the impact of a 3-foot drop
■ Test congratulatory and disheartening tunes play critical roles
- Shoulds:
■ Test aesthetics - are we all happy with the way it looks?
■ Test size - should fit in the palm of a hand
- Mays:
■ Test “wireless” charging capabilities - ensure charging contacts are working properly

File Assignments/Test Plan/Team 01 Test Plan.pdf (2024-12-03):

Example Test Plan: LED 20

Test Author: Team 01
Test Case Name: | Verify Structural Integrity of 3D-printed LED20 Enclosure | Test ID #: | LED20-01
Description: | This test case assesses the durability and structural integrity of the LED20 die's 3D-printed enclosure under various stress conditions. The 3D-printed enclosure should withstand normal rolling, minor impacts, and moderate pressure without cracking, deforming, or causing internal components to shift or become damaged. These tests ensure that the enclosure is robust enough for practical use as a rolling die. | Type: | □ white box ☑ black box □ ________

Tester Information
| Name of Tester: | Henry, Brad, Caleb, Chris | Date: | 12/2/2024
| HW/SW Version: | 1.0 | Time: | 04:00 PM
| Setup: | Ensure the enclosure is secure, correctly keyed, and all pegs inserted into corresponding holes, record any existing imperfections before starting and take baseline images of the enclosure for post-test comparison
S T E P | Action | Expected Result | P A S S | F A I L | N / A | Comments
1 | Roll LED20 onto a flat surface from a height of 1 foot | The device lands and comes to rest naturally
2 | Observe the impact of the role | The device is physically unaltered
3 | Repeat steps 1-2 for 50 rolls | The device is physically unaltered
4 | Take pictures of the device | The device is physically unaltered
5 | Drop LED20 onto a flat surface from a height of 3 feet | The device lands and comes to rest naturally
6 | Observe impact of a drop | The device is physically unaltered
7 | Repeat steps 5-6 for 30 drops | The device is physically unaltered
8 | Take pictures of the device | The device is physically unaltered
9
| Overall test result:
2024-11-25 | Page 1 of 2

Example Matrix Test (for varying parameters)

Test Author: Team 01

Test Case Name: | Verify LED20 Die Face Illumination with Orientation Detection | Test ID #: | LED20-02
Description: | This test case verifies that all embedded LEDs in the LED20 correctly illuminate the upright face of the die after experiencing SMD when it is oriented upright on a flat surface. This test ensures that the LED correctly identifies the orientation of the die and activates only for the face in the position. | Type: | □ white box ☑ black box □ _____________

Tester Information

| Name of Tester: | Henry, Brad, Caleb, Chris | Date: | 12/5/2024
| HW/SW Version: | 1.0 | Time: | 5:00 PM
| Setup: | Ensure ESP32-C6 has power, LSM6D032 is correctly reporting data, all LEDs operational
T E S T | INPUTS | EXPECTED OUTPUTS | P A S S | F A I L | N / A | Comments
1 | Roll LED20 on flat surface | Device lands and comes to rest naturally
2 | Examine upright face of die | Upright face is illuminated
3 | Record number rolled and P/F
4 | Repeat Steps 1-3 until all faces of die have been rolled 10 times | Upright face illuminates every time
| Overall test result:
2024-11-25 | Page 2 of 2

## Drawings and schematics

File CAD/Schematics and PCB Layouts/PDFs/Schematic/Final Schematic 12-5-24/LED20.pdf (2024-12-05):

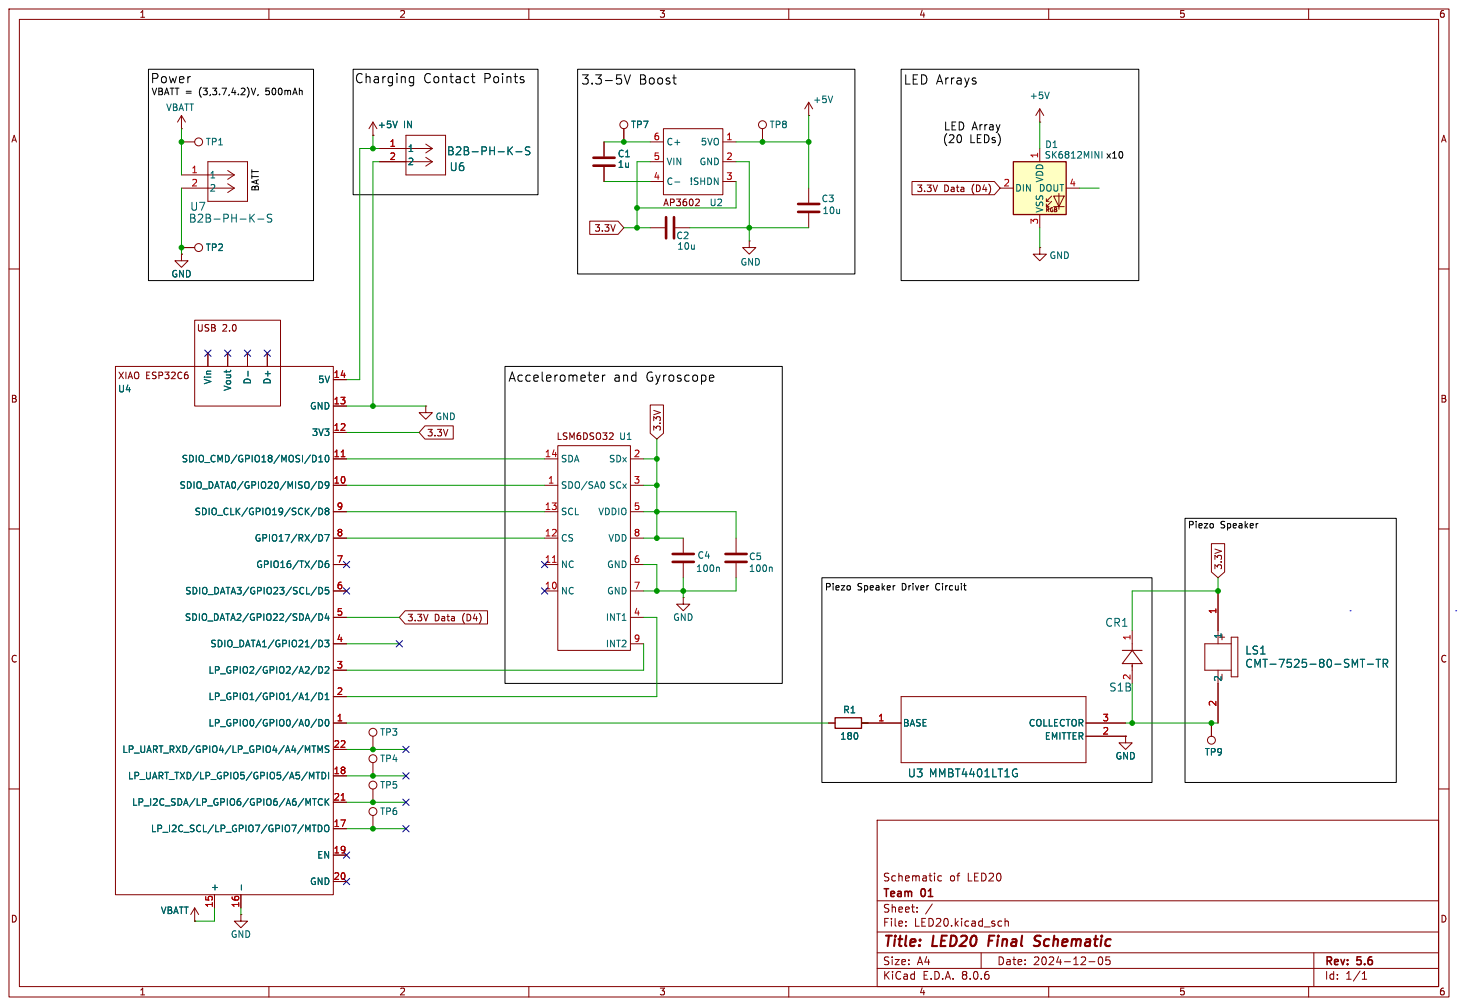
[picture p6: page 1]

Id: 1/1 Title: LED20 Final Schematic

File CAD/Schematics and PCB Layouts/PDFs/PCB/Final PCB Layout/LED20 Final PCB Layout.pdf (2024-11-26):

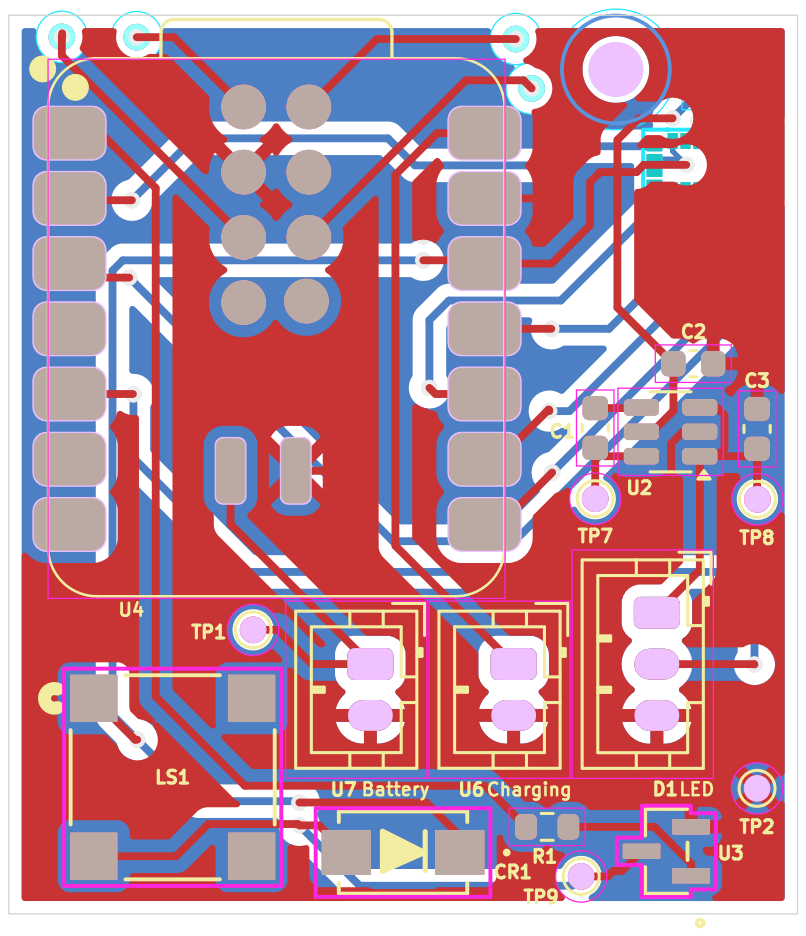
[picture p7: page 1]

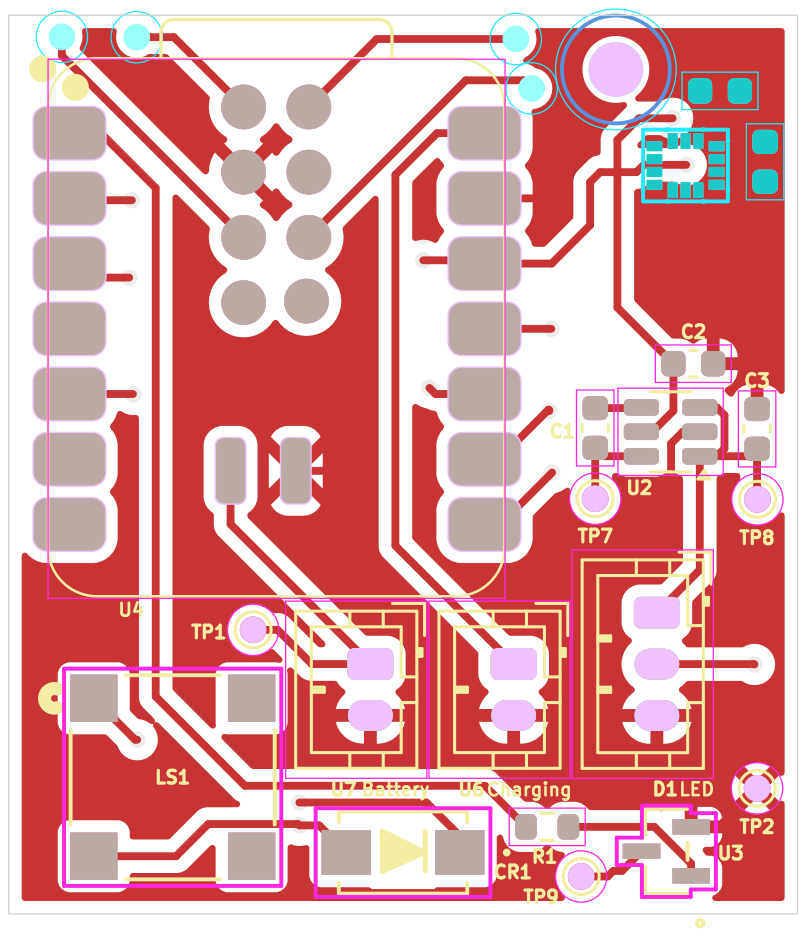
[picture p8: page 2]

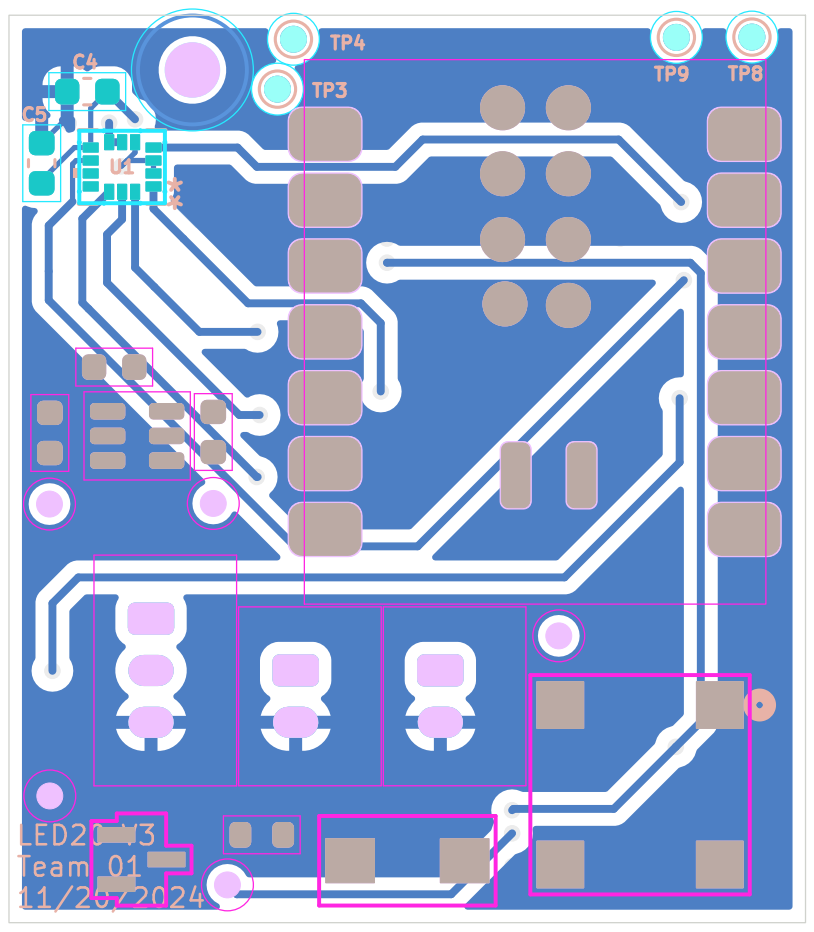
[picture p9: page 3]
D Date: 2024-11-21 KiCad; E.D.A. 8.0.6 Size: A4; Rev: 5; Id: 1/1 Title: LED20 Final PCB Layout File: LED20.kicad_pcb Sheet: Team 01 PCB Layout of; LED20; TP8 LED20; V3 Team

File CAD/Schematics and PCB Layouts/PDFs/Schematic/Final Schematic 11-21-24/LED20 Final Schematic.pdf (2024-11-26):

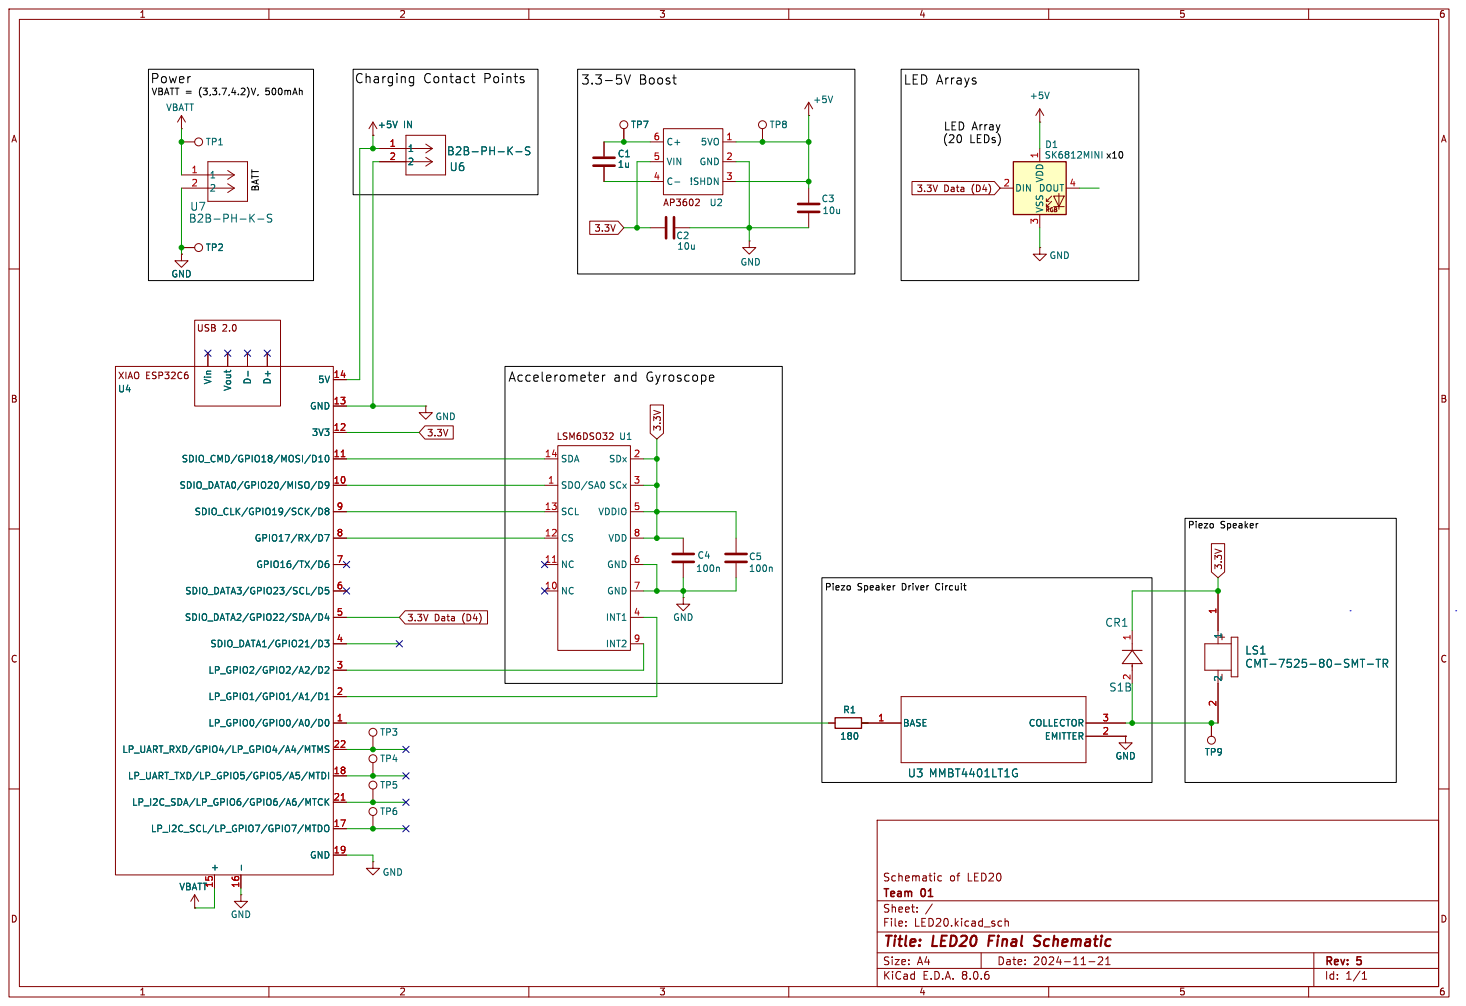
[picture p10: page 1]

Id: 1/1 Title: LED20 Final Schematic

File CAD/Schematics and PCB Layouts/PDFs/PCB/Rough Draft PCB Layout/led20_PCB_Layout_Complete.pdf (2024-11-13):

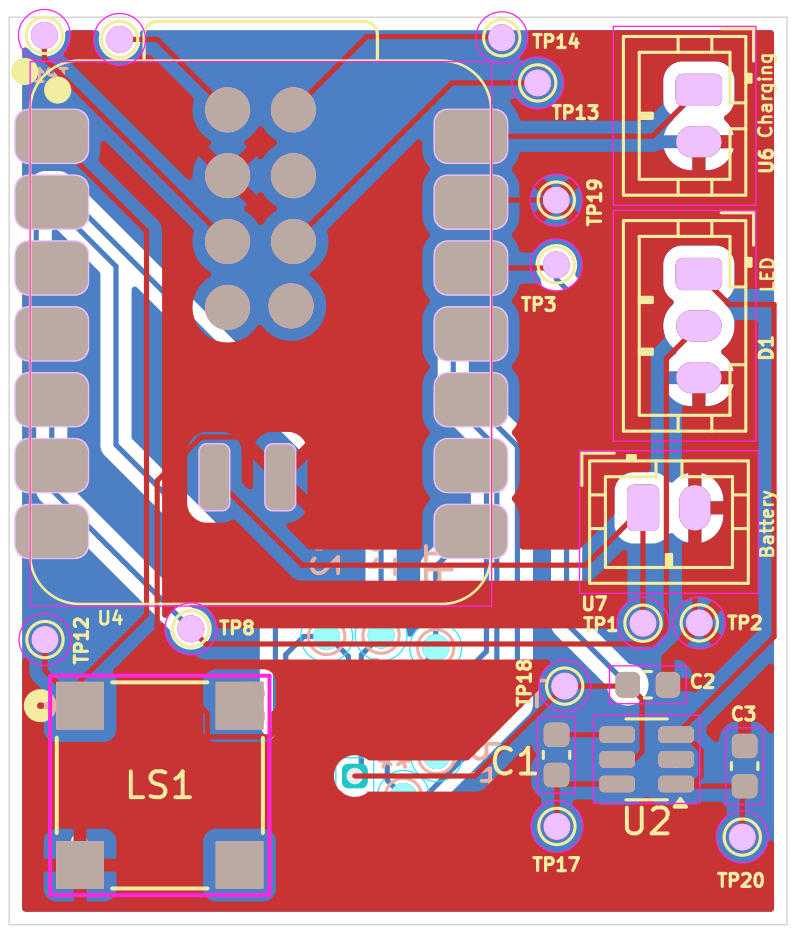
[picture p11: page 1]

Id: 1/1 Title: LED20 Updated Schematic

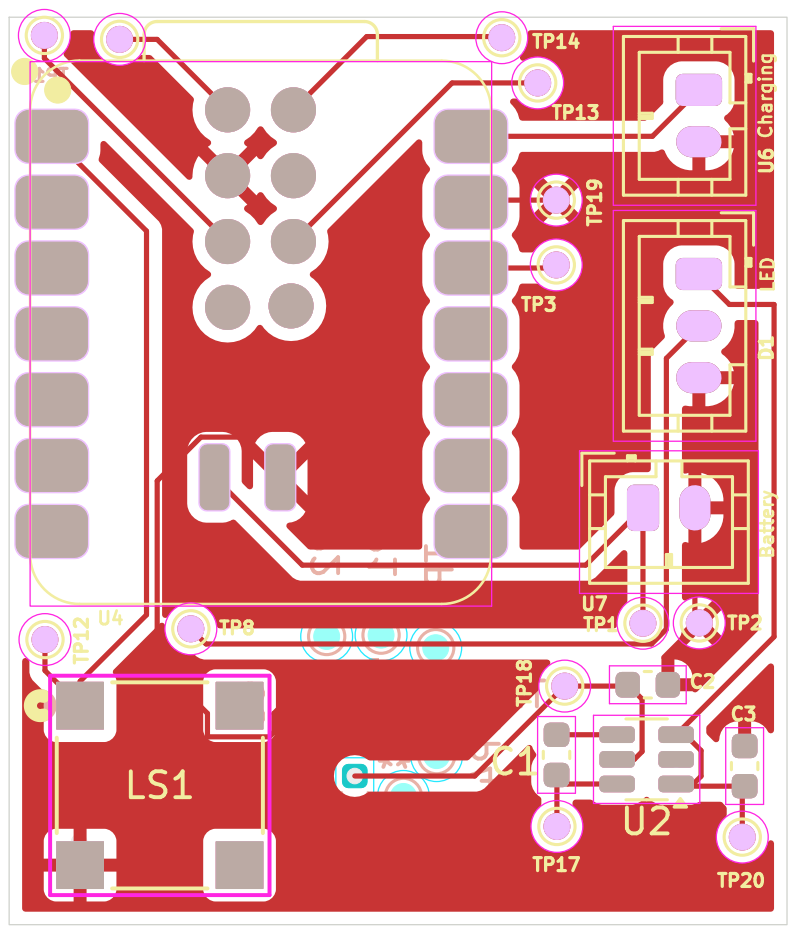
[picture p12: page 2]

Id: 1/1 Title: LED20 Updated Schematic

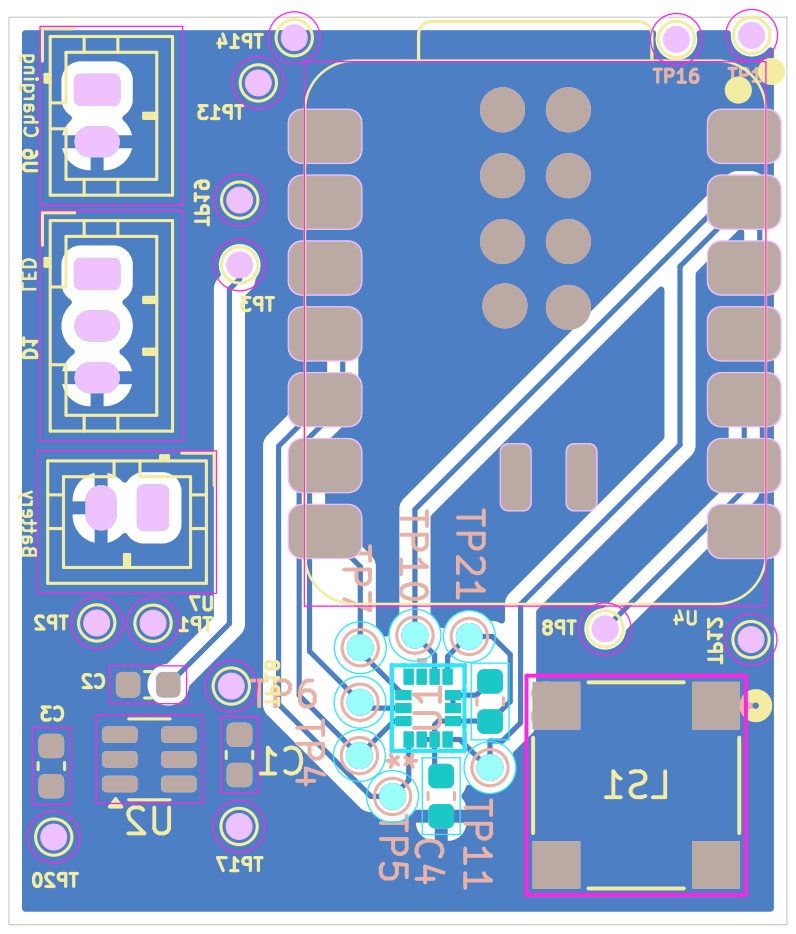
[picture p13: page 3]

Id: 1/1 Title: LED20 Updated Schematic

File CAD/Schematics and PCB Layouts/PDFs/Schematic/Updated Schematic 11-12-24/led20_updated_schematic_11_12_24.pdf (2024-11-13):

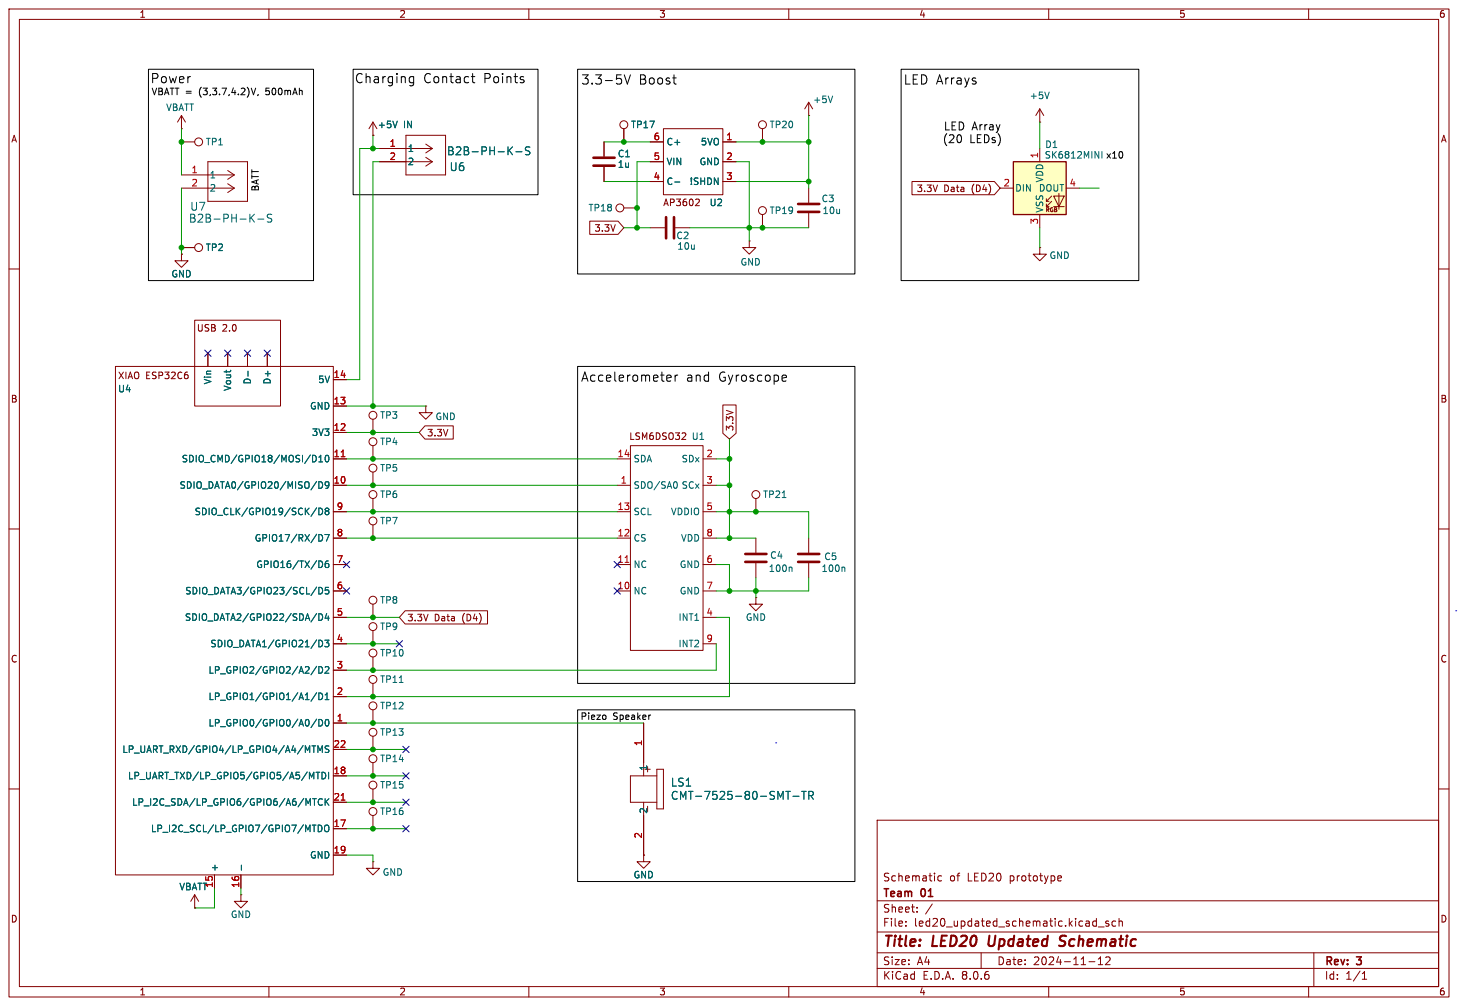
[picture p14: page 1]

x10 Charging Contact Points BATT

Id: 1/1 Title: LED20 Updated Schematic

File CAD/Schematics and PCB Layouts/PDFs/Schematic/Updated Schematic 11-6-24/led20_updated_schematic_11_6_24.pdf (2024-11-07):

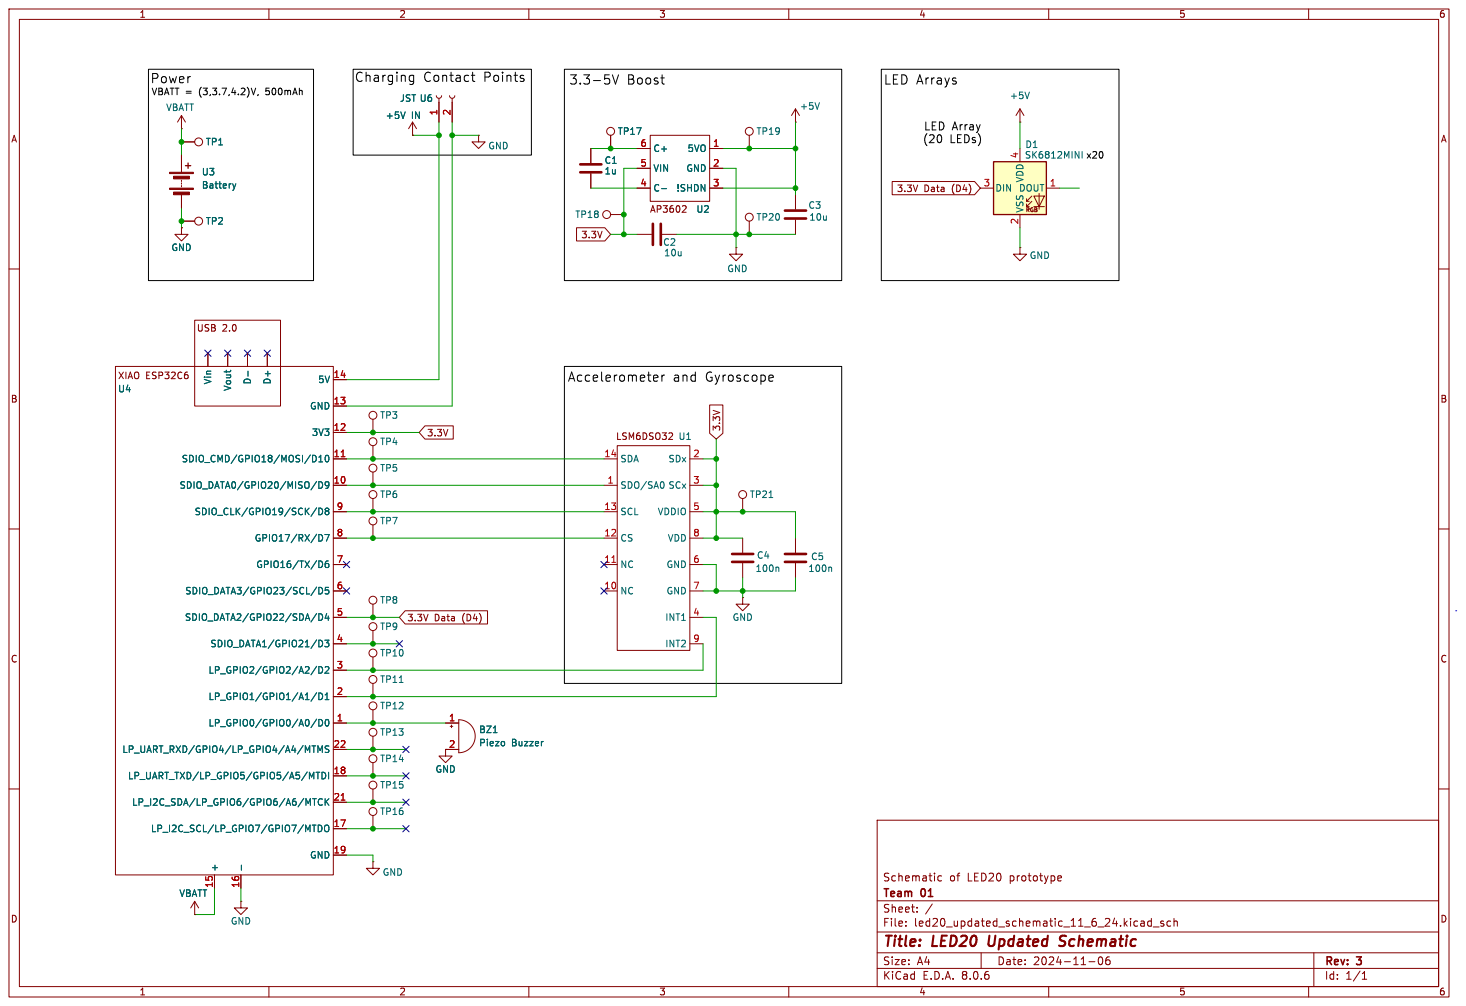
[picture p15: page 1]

INT1 4 VDDIO 5 GND 6 GND 7 VDD 8

Id: 1/1 Title: LED20 Updated Schematic

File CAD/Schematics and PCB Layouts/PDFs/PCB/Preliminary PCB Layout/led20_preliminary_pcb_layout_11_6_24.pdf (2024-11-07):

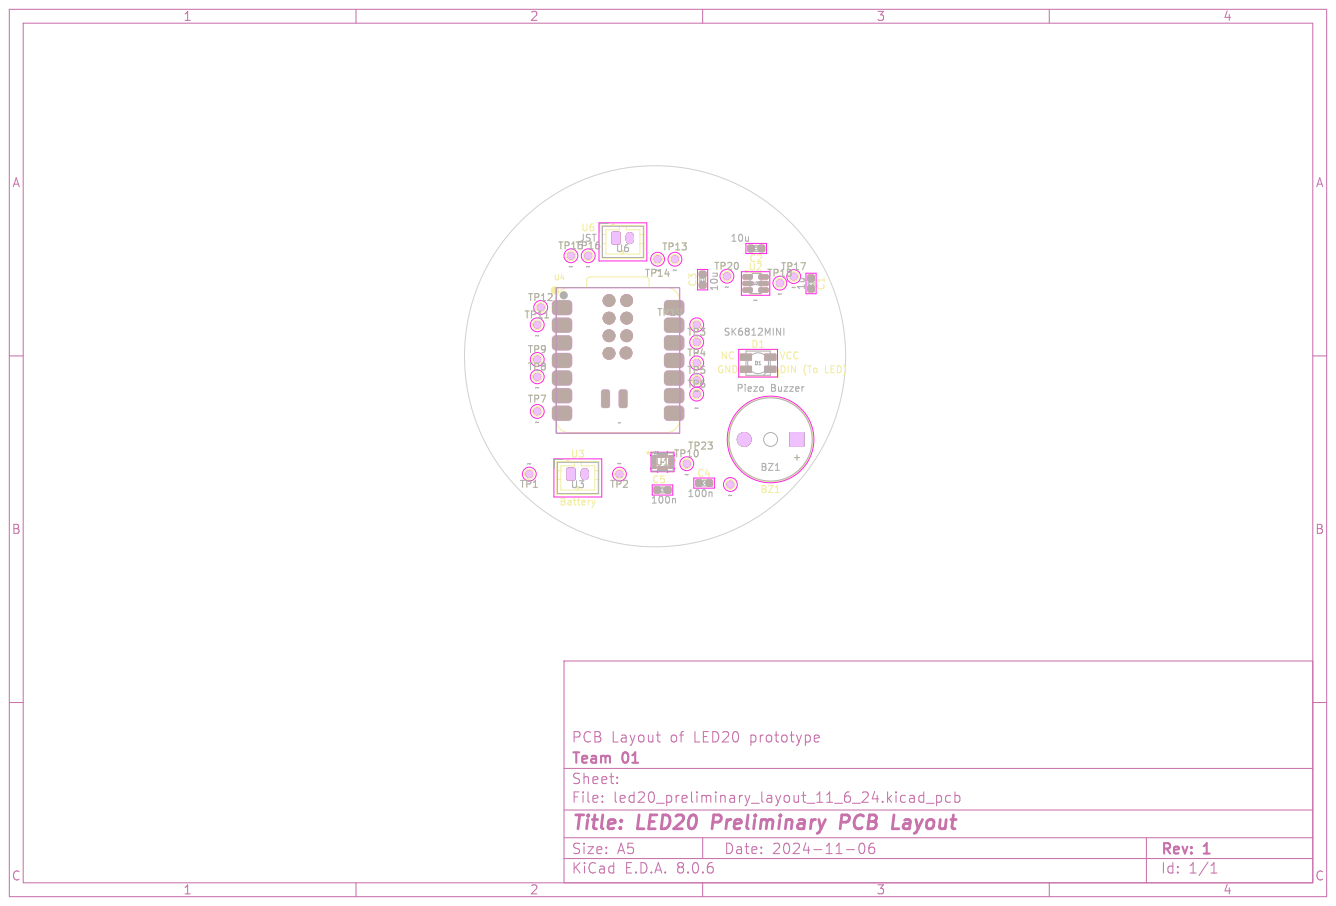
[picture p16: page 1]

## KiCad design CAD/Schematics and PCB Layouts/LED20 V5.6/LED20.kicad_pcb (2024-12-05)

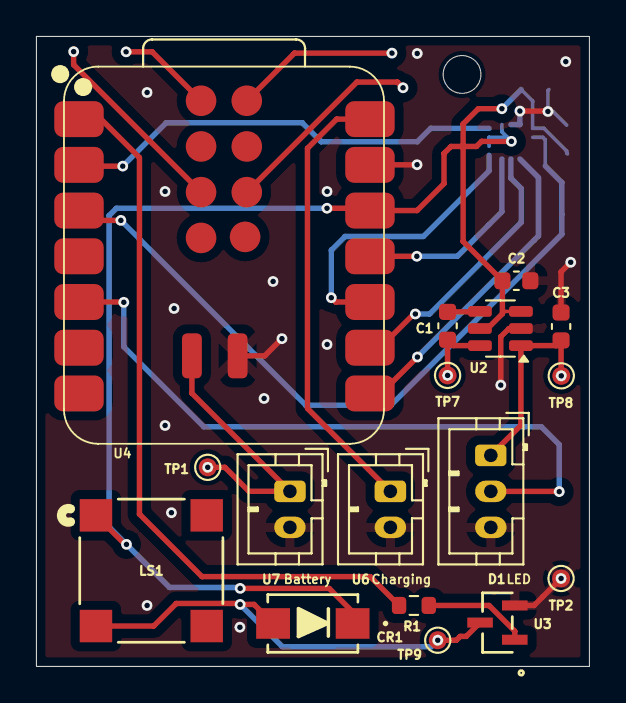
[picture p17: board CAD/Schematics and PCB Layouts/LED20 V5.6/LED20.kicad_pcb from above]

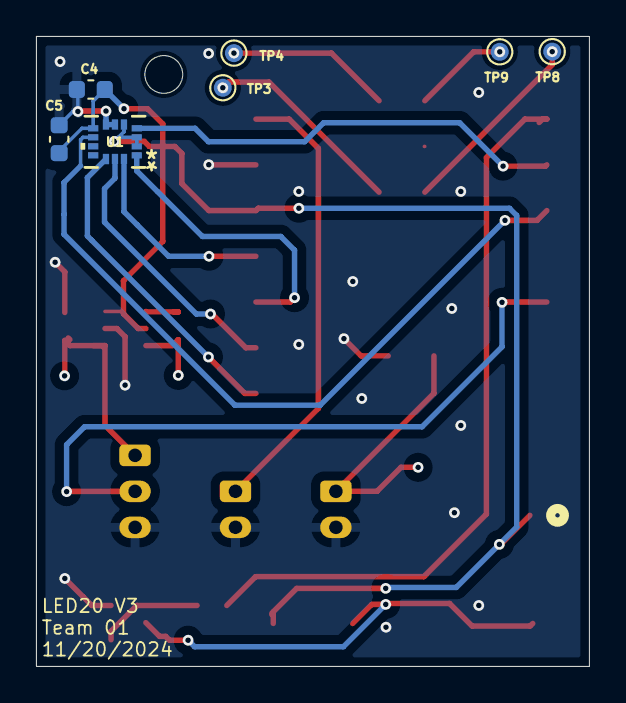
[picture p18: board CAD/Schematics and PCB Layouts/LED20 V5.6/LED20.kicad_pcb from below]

Board: 2 copper layers, 30.7 x 35.0 mm, 24 parts (7 on the bottom side), 17 nets.

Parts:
C1: 1u; C_0603_1608Metric
C2, C3: 10u; C_0603_1608Metric
C4, C5: 100n; C_0603_1608Metric
CR1: S1B; SMA_403AE_OSI
D1: SK6812MINI; JST_PH_B3B-PH-K_1x03_P2.00mm_Vertical
LS1: CMT-7525-80-SMT-TR; CMT-7525-80-SMT-TR_CUD
R1: 180; R_0603_1608Metric
TP1, TP2, TP3, TP4, TP5, TP6, TP7, TP8, TP9: TestPoint_Pad_D1.0mm
U1: LGA-14L_2P5X3X0P83_STM-L
U2: ChargePump
U3: MMBT4401LT1G; SOT-23_ONS
U4: XIAO-ESP32-C6-SMD
U6, U7: B2B-PH-K-S; JST_PH_B2B-PH-K_1x02_P2.00mm_Vertical

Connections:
3.3V: C2.1, C4.2, C5.2, CR1.1, LS1.1, U1.2 (SDx), U1.3 (SCx), U1.5 (VDDIO), U1.8 (VDD), U2.3 (!SHDN), U2.5 (VIN), U4.12 (3V3)
3.3V Data (D4): D1.2 (DIN), U4.5 (SDIO_DATA2/GPIO22/SDA/D4)
+5V: C3.2, D1.1 (VDD), TP8.1, U2.1 (5VO)
+5V IN: U4.14 (5V), U6.1
GND: C2.2, C3.1, C4.1, C5.1, D1.3 (VSS), TP2.1, U1.6 (GND), U1.7 (GND), U2.2 (GND), U3.2 (EMITTER), U4.13 (GND), U4.16 (-), U6.2, U7.2
unnamed: U1.12 (CS), U4.8 (GPIO17/RX/D7)
unnamed: U1.4 (INT1), U4.2 (LP_GPIO1/GPIO1/A1/D1)
unnamed: U1.9 (INT2), U4.3 (LP_GPIO2/GPIO2/A2/D2)
unnamed: U1.13 (SCL), U4.9 (SDIO_CLK/GPIO19/SCK/D8)
unnamed: U1.14 (SDA), U4.11 (SDIO_CMD/GPIO18/MOSI/D10)
unnamed: U1.1 (SDO/SA0), U4.10 (SDIO_DATA0/GPIO20/MISO/D9)
unnamed: C1.1, TP7.1, U2.6 (C+)
unnamed: C1.2, U2.4 (C-)
unnamed: R1.2, U3.1 (BASE)
unnamed: CR1.2, LS1.2, TP9.1, U3.3 (COLLECTOR)
unnamed: R1.1, U4.1 (LP_GPIO0/GPIO0/A0/D0)
VBATT: TP1.1, U4.15 (+), U7.1

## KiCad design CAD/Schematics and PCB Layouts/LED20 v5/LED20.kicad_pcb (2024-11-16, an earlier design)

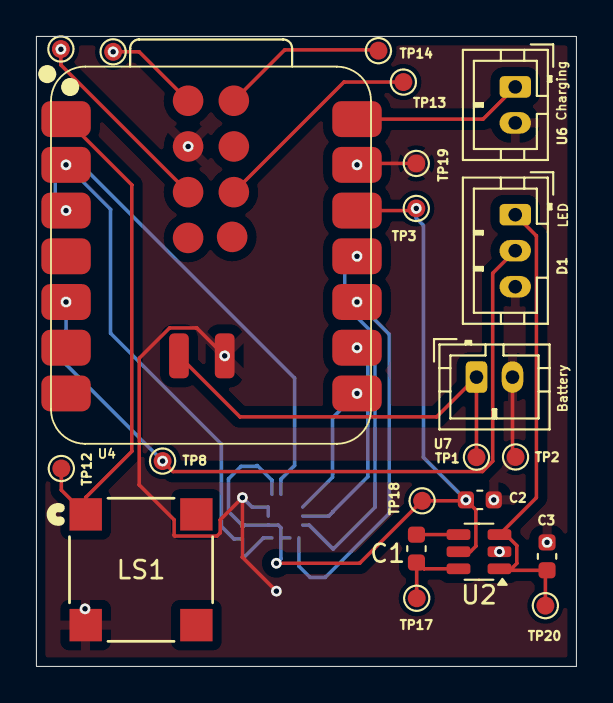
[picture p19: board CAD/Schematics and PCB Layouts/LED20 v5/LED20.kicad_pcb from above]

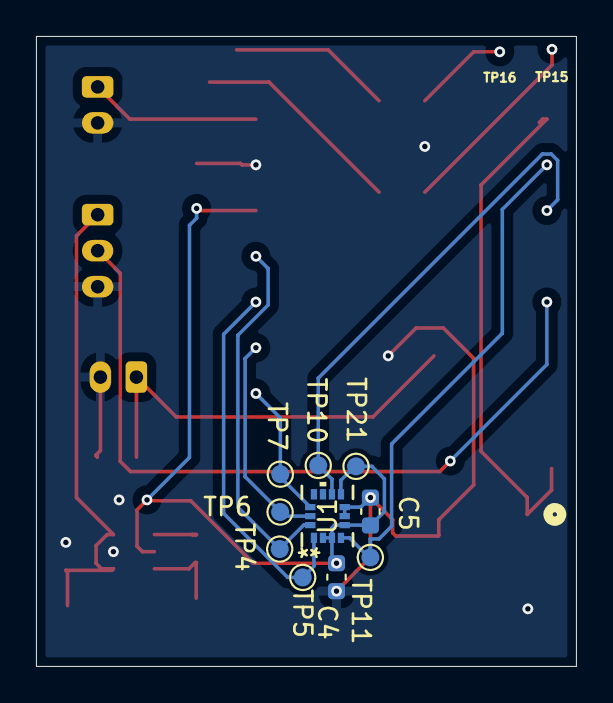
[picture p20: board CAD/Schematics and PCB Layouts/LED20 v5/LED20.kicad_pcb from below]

Board: 2 copper layers, 30.0 x 35.0 mm, 32 parts (10 on the bottom side), 15 nets.

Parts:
C1: 1u; C_0603_1608Metric
C2, C3: 10u; C_0603_1608Metric
C4, C5: 100n; C_0603_1608Metric
D1: SK6812MINI; JST_PH_B3B-PH-K_1x03_P2.00mm_Vertical
LS1: CMT-7525-80-SMT-TR; CMT-7525-80-SMT-TR_CUD
TP1, TP2, TP3, TP4, TP5, TP6, TP7, TP8, TP10, TP11, TP12, TP13, TP14, TP15, TP16, TP17, TP18, TP19, TP20, TP21: TestPoint_Pad_D1.0mm
U1: LGA-14L_2P5X3X0P83_STM-L
U2: ChargePump
U4: XIAO-ESP32-C6-SMD
U6, U7: B2B-PH-K-S; JST_PH_B2B-PH-K_1x02_P2.00mm_Vertical

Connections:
3.3V: C2.1, C4.2, C5.2, TP3.1, TP18.1, TP21.1, U1.2 (SDx), U1.3 (SCx), U1.5 (VDDIO), U1.8 (VDD), U2.5 (VIN), U4.12 (3V3)
3.3V Data (D4): D1.2 (DIN), TP8.1, U4.5 (SDIO_DATA2/GPIO22/SDA/D4)
+5V: C3.2, D1.1 (VDD), TP20.1, U2.1 (5VO), U2.3 (!SHDN)
+5V IN: U4.14 (5V), U6.1
GND: C2.2, C3.1, C4.1, C5.1, D1.3 (VSS), LS1.2, TP2.1, TP19.1, U1.6 (GND), U1.7 (GND), U2.2 (GND), U4.13 (GND), U4.16 (-), U4.19 (GND), U6.2, U7.2
unnamed: TP7.1, U1.12 (CS), U4.8 (GPIO17/RX/D7)
unnamed: TP11.1, U1.4 (INT1), U4.2 (LP_GPIO1/GPIO1/A1/D1)
unnamed: TP10.1, U1.9 (INT2), U4.3 (LP_GPIO2/GPIO2/A2/D2)
unnamed: TP6.1, U1.13 (SCL), U4.9 (SDIO_CLK/GPIO19/SCK/D8)
unnamed: TP4.1, U1.14 (SDA), U4.11 (SDIO_CMD/GPIO18/MOSI/D10)
unnamed: TP5.1, U1.1 (SDO/SA0), U4.10 (SDIO_DATA0/GPIO20/MISO/D9)
unnamed: C1.1, TP17.1, U2.6 (C+)
unnamed: C1.2, U2.4 (C-)
unnamed: LS1.1, TP12.1, U4.1 (LP_GPIO0/GPIO0/A0/D0)
VBATT: TP1.1, U4.15 (+), U7.1

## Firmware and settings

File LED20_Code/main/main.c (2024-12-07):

/* LED20
 * @author: ECE 411 Team 01
 * 
 * 
 * This program connects a Seeed Studio ESP32-C6 to
 * a LSM6DSO32 Accelerometer/Gyroscope IC. The end goal
 * is to create a D20 or 20-sided die that illuminates 
 * the top-most side after being rolled. If a 1 or a 20
 * are rolled, the die then plays a specialized animation 
 * on the LEDs and a sound or melody on the piezo speaker.
 * 
 * 
 * 
*/


#include <stdio.h>
#include <unistd.h>
#include <string.h>
#include <math.h>
#include "driver/i2c_master.h"
#include "driver/gpio.h"
#include "hal/spi_types.h"
#include "driver/spi_common.h"
#include "driver/spi_master.h"
#include "driver/rmt_common.h"
#include "driver/rmt_tx.h"
#include "driver/rmt_types.h"
#include "esp_log.h"
#include "freertos/FreeRTOS.h"
#include "freertos/task.h"
#include "esp_sleep.h"
#include "driver/ledc.h"
#include "esp_timer.h"


#include "defines.c"

// SPI connection and classifications

#define SPI_HOST SPI2_HOST      // SPI1 not available

#define PIN_MISO 20 // MISO GPIO of host
#define PIN_MOSI 18 // MOSI GPIO of host
#define PIN_SCK 19  // SCK GPIO of host
#define PIN_CS 17   // CS GPIO of host
#define PIN_INT1 1  // GPIO Input for interrupt 1
#define PIN_INT2 2  // GPIO Input for interrupt 2


// LED Connection and classifications

#define LED_NORTH 22 // LED Data Out pin for North Hemisphere
#define LED_NORTH_CHAIN 20 // Number of LEDs in North Hemisphere


// Sensor classifications and constants

#define SPI_CLOCK_SPEED 6           // SPI transfer speed in MHz
#define ACCEL_SENSITIVITY_4G 0.000122
#define GYRO_SENSITIVITY_500DPS 0.0175
#define Z_OFFSET_ACC -0.007
#define Z_OFFSET_GYRO -178
#define TOLERANCE 0.2

#define SENSOR_DATA_GRAB_REPEATS 10

// Piezo speaker setup
#define PIEZO_PIN 0

// Testing and debugging
#define BLINK_USEC  250000
#define LED_HEARTBEAT 15
#define TIMER_DUR 40

bool heartbeat_state = false;
bool first_inact = false;
static bool interrupt_triggered = false;
static bool active_detect = false;
static bool inactive_detect = false;
volatile bool is_drdy = true;
int8_t read_burst[12];
int8_t accel_temp_burst[8];
float accel_results[3];
TaskHandle_t drdy_task_handle = NULL;
static esp_timer_handle_t timer_handle = NULL;

const float faces[NUM_FACES][3] = {
    FACE_1, FACE_2, FACE_3, FACE_4, FACE_5,
    FACE_6, FACE_7, FACE_8, FACE_9, FACE_10,
    FACE_11, FACE_12, FACE_13, FACE_14, FACE_15,
    FACE_16, FACE_17, FACE_18, FACE_19, FACE_20
};
                        // 20  8 10  2 12 15  7 17  3 16  6 14  4 18  5 13 11 19  9  1
// Put LED order here,      1  2  3  4  5  6  7  8  9 10 11 12 13 14 15 16 17 18 19 20
const int led_order[20] = {19, 3, 8,12,14,10, 6, 1,18, 2,16, 4,15,11, 5, 9, 7,13,17,0};


// Global LED value 
uint8_t led_red[LED_NORTH_CHAIN * 3];
uint8_t led_green[LED_NORTH_CHAIN * 3];
uint8_t led_blue[LED_NORTH_CHAIN * 3];
uint8_t led_off[LED_NORTH_CHAIN * 3];
uint8_t led_current[LED_NORTH_CHAIN * 3];

// SPI bus device setup
spi_device_handle_t accel;              // Set up accel/gyro device 
spi_device_interface_config_t accel_config = {

    .clock_speed_hz = SPI_CLOCK_SPEED * 1000 * 1000,    // Set clock speed (Hz)
    .spics_io_num = PIN_CS,                             // Set CS pin
    .mode = 3,                                          // According to datasheet page 30
    .queue_size = 12,                                   // Max number of queued transactions
    .command_bits = 8,                                  // Specify 8 bits for command (register address)
    .address_bits = 0,                                  // Set address_bits to 0 since only cmd is used for address

};


// RMT transfer setup
rmt_channel_handle_t rmt_LED_north = NULL;
rmt_tx_channel_config_t rmt_north_config = {
        
    .clk_src = RMT_CLK_SRC_DEFAULT,
    .gpio_num = LED_NORTH,
    .mem_block_symbols = (128),
    .resolution_hz = 10 * 1000 * 1000,
    .trans_queue_depth = 1,
    .flags.invert_out = false,
    .flags.with_dma = false,
};

static rmt_encoder_handle_t bytes_encoder = NULL;
rmt_bytes_encoder_config_t bytes_encoder_config = {
    .bit0 = { .level0 = 1, .duration0 = T0H, .level1 = 0, .duration1 = T0L },   // 0 bit: 0.3 µs high, 0.9 µs low
    .bit1 = { .level0 = 1, .duration0 = T1H, .level1 = 0, .duration1 = T1L },   // 1 bit: 0.6 µs high, 0.6 µs low
    .flags.msb_first = true, // SK6812MINI typically sends MSB first as well
};

ledc_timer_config_t piezo_timer = {
        .speed_mode = LEDC_LOW_SPEED_MODE,   // High-speed mode
        .timer_num = LEDC_TIMER_0,           // Timer 0
        .duty_resolution = LEDC_TIMER_10_BIT,// Resolution of PWM duty (0-1023)
        .freq_hz = 2000,                     // Frequency in Hertz (e.g., 2 kHz for a tone)
        .clk_cfg = LEDC_AUTO_CLK             // Use the default clock source
};

ledc_channel_config_t piezo_channel = {
        .gpio_num = PIEZO_PIN,             // GPIO number for the buzzer
        .speed_mode = LEDC_LOW_SPEED_MODE,  // High-speed mode
        .channel = LEDC_CHANNEL_0,           // Use channel 0
        .timer_sel = LEDC_TIMER_0,           // Select timer 0
        .duty = 512,                         // Initial duty cycle (50%)
        .hpoint = 0                          // Hardware timer high point (0 by default)
};

// Function prototypes

void w_trans (uint16_t address, uint16_t data );
uint8_t r_trans(uint8_t address);
void led_w(uint8_t *led_data);
void IRAM_ATTR gpio_isr_handler(void* arg);
void IRAM_ATTR drdy_isr_handler(void* arg);
void handle_activity_task(void* arg);
void handle_drdy_task(void* arg);
void activity_sequence();
void inactivity_sequence();
void accel_get_modes();
int get_face();
int compare_vectors(const float a[3], const float b[3], float tolerance);
void light_face(int face);
void led_test();
void play_tune(int (*tune)[2], int num_notes);
void initialize_timer();
void timer_sleep(void *arg);
void stop_timer();
void restart_timer(uint64_t interval_us);
void roll_1();
void roll_20();

int app_main(void)
{
    // Local variable declarations
    int8_t z_offset_acc = (int8_t)(Z_OFFSET_ACC * USR_OFFSET_FACTOR+0.5);

    // ISR setup
    gpio_config_t activity_conf = {
        .intr_type = GPIO_INTR_ANYEDGE,
        .mode = GPIO_MODE_INPUT,
        .pin_bit_mask = (1ULL << PIN_INT2),
        .pull_down_en = GPIO_PULLDOWN_DISABLE,
        .pull_up_en = GPIO_PULLUP_DISABLE,
    };

    gpio_config_t drdy_conf = {
        .intr_type = GPIO_INTR_POSEDGE,
        .mode = GPIO_MODE_INPUT,
        .pin_bit_mask = (1ULL << PIN_INT1),
        .pull_down_en = GPIO_PULLDOWN_DISABLE,
        .pull_up_en = GPIO_PULLUP_DISABLE,

    };
    
    gpio_config_t heartbeat_conf = {
        .pin_bit_mask = (1ULL << LED_HEARTBEAT), // Pin mask for GPIO15
        .mode = GPIO_MODE_OUTPUT,                 // Set as output mode
        .pull_up_en = GPIO_PULLUP_DISABLE,        // Disable pull-up
        .pull_down_en = GPIO_PULLDOWN_DISABLE,    // Disable pull-down
        .intr_type = GPIO_INTR_DISABLE            // Disable interrupts
    };
    gpio_config(&heartbeat_conf);

    


    // Off LED setup
    for (int i = 0; i < LED_NORTH_CHAIN * 3; i++){
        led_off[i]=0;
    }

    // Red LED setup
    for (int i = 0; i < LED_NORTH_CHAIN; i++){

        led_red[3*i]   = 0x00;
        led_red[3*i+1] = 0xF;
        led_red[3*i+2] = 0x00;
    }

    // Green LED setup
    for (int i = 0; i < LED_NORTH_CHAIN; i++){

        led_green[3*i]   = 0xF;
        led_green[3*i+1] = 0x00;
        led_green[3*i+2] = 0x00;
    }

    // Blue LED setup
    for (int i = 0; i < LED_NORTH_CHAIN; i++){

        led_blue[3*i]   = 0x00;
        led_blue[3*i+1] = 0x00;
        led_blue[3*i+2] = 0xF;
    }

    // LED RMT setup
    if (rmt_LED_north) {
        rmt_del_channel(rmt_LED_north);
        rmt_LED_north = NULL;   
    }   
    ESP_ERROR_CHECK(rmt_new_tx_channel(&rmt_north_config, &rmt_LED_north));
    ESP_ERROR_CHECK(rmt_new_bytes_encoder(&bytes_encoder_config, &bytes_encoder));


    // SPI bus and device setup
    spi_bus_config_t spi_bus_cfg = {        // configure SPI bus properties and pins
        .miso_io_num = PIN_MISO,            // Set up IO pins 
        .mosi_io_num = PIN_MOSI,
        .sclk_io_num = PIN_SCK,
        .quadwp_io_num = -1,
        .quadhd_io_num = -1,
    };



    ESP_ERROR_CHECK(spi_bus_initialize(SPI_HOST, &spi_bus_cfg, SPI_DMA_CH_AUTO));
    

    ESP_ERROR_CHECK(spi_bus_add_device(SPI2_HOST, &accel_config ,&accel ));
    ESP_LOGD("SETUP","SPI was set up with no errors");
    
    vTaskDelay(pdMS_TO_TICKS(50));

    uint8_t whoami = r_trans(0x0F);
    ESP_LOGD("WHOAMI", "Value: 0x%02X", whoami);
    if (whoami != 0x6C){
        ESP_LOGE("WHOAMI", "DATA READ FAILURE");
        return -1;
    }
    

    // Reset and intialize sensors
    ESP_LOGD("SETUP","Initializing Accel and Gyro");
    w_trans(CTRL3_C, 0x1);    // Reset the sensor
    w_trans(CTRL1_XL, 0x92);    // Set the speed and rate of the accel
    w_trans(CTRL2_G, 0x94);     // Set the speed and rate of the gyro
    w_trans(CTRL6_C, 0x00);     // Set high performance for accel and xyz offset resolution (2^-10)
    w_trans(CTRL7_G, 0x02);     // Enable User offsets for low pass filter
    w_trans(CTRL8_XL, 0x00);    // Set up Low Pass Filter for accel

    // Set up DRDY interrupt detection on INT1
    w_trans(INT1_CTRL, 0x01); // Accelerometer data-ready interrupt on INT1

    ESP_LOGD("SETUP","Initializing interrupt detection for Activity/Inactivity");
    // Set up Inactivity Detection intterupt on INT2
    w_trans(WAKEUP_DUR, 0x08);       // Set inactivity time 
    w_trans(WAKEUP_THS, 0x10);       // Set inactivity threshold
    w_trans(TAP_CFG0, 0x20);         // Set sleep-change notification
    w_trans(TAP_CFG2, 0xE0);         // Enable interrupt
    w_trans(MD2_CFG, 0x80);          // Route interrupt to INT2
    w_trans(Z_OFS_ACC, z_offset_acc); // Set the calculated z offset



    led_w(led_green);
    vTaskDelay(pdMS_TO_TICKS(1000)); // Delay for 2000 ms
    led_w(led_off);
    initialize_timer();

    ESP_LOGD("SETUP","Activating interrupt handling for Activity/Inactivity interrupts");
    gpio_config(&activity_conf);
    gpio_install_isr_service(0);
    gpio_isr_handler_add(PIN_INT2,gpio_isr_handler, NULL);
    xTaskCreate(handle_activity_task, "handle_activity_task", 4096, NULL, 10, NULL);
    
    gpio_config(&drdy_conf);
    gpio_isr_handler_add(PIN_INT1, drdy_isr_handler, NULL);
    xTaskCreate(handle_drdy_task, "handle_drdy_task", 4096, NULL, 10, &drdy_task_handle);
    
    
    ESP_LOGD("SETUP","Setup complete!");
    ledc_timer_config(&piezo_timer);
    ledc_channel_config(&piezo_channel);
    vTaskDelay(pdMS_TO_TICKS(50)); // Delay for 100 ms
    ledc_stop(LEDC_LOW_SPEED_MODE, LEDC_CHANNEL_0, 0); // Turn off PWM 
    //led_test();
    
    //play_tune(tune, 9);

    
    while(1){

        if(heartbeat_state) {
            gpio_set_level(LED_HEARTBEAT, 1);
            heartbeat_state = false;
        }
        else {
            gpio_set_level(LED_HEARTBEAT, 0);
            heartbeat_state = true;
        }
        usleep(BLINK_USEC);
       
    }

    return 0;
    
}

void w_trans (uint16_t address, uint16_t data ){
    
    spi_transaction_t transfer = { 0 };
    
    transfer.length = 8;
    ESP_LOGD("WRITE_TRANS", "Setting flags");
    transfer.flags = SPI_TRANS_USE_TXDATA;
    ESP_LOGD("WRITE_TRANS", "Setting address");   
    transfer.cmd = address;
    ESP_LOGD("WRITE_TRANS", "Setting data");
    transfer.tx_data[0] = data;
    ESP_LOGD("WRITE_TRANS", "Attempting write at address 0x%02X", address);
    ESP_ERROR_CHECK(spi_device_transmit(accel, &transfer) );
    ESP_LOGD("WRITE_TRANS", "Write at address 0x%02X completed", address);

    return;

}
 
uint8_t r_trans(uint8_t address){

    spi_transaction_t transfer = {0};
    transfer.length = 8;
    transfer.rxlength = 8;
    ESP_LOGD("READ_TRANS", "Setting flags");
    transfer.flags = SPI_TRANS_USE_RXDATA;
    ESP_LOGD("READ_TRANS", "Setting address");   
    transfer.cmd = (address | 0x80) ;
    ESP_LOGD("READ_TRANS", "Attempting read at address 0x%02x", address);
    ESP_ERROR_CHECK(spi_device_transmit(accel, &transfer));

    ESP_LOGD("READ_TRANS", "Read at address 0x%02X completed", address);

    return transfer.rx_data[0];

}


void r_accel(){

    if (!is_drdy) {
        while(!is_drdy);
        vTaskDelay(pdMS_TO_TICKS(50));
    }
    is_drdy = false;

    spi_transaction_t trans[3] = {};
    spi_transaction_t *receive[3] = {};

    ESP_LOGD("ACCEL_READ", "Setting up read transaction 0");
    trans[0].length = 32;                                   // Each transaction has a length of 4 bytes (32 bits)
    trans[0].rxlength = 32;                                 
    trans[0].cmd = ( ACCEL_X_LOW  | 0x80 );                 // Increment starting addres by 4 each iteration
    trans[0].flags = SPI_TRANS_USE_RXDATA;                  // Use rx_data until DMA access becomes necessary
    trans[0].rx_buffer = NULL;
    trans[0].tx_buffer = NULL;
    ESP_LOGD("ACCEL_READ", "Queueing read transaction 0");
    ESP_ERROR_CHECK(spi_device_queue_trans(accel, &trans[0], portMAX_DELAY));


    ESP_LOGD("ACCEL_READ", "Setting up read transaction 1");
    trans[1].length = 16;
    trans[1].rxlength = 16;
    trans[1].cmd = (ACCEL_Z_LOW | 0x80);
    trans[1].flags = SPI_TRANS_USE_RXDATA;
    trans[1].rx_buffer = NULL;
    trans[1].tx_buffer = NULL;
    ESP_LOGD("ACCEL_READ", "Queueing read transaction 1");
    ESP_ERROR_CHECK(spi_device_queue_trans(accel, &trans[1], portMAX_DELAY));


    ESP_LOGD("ACCEL_READ", "Setting up read transaction 2");
    trans[2].length = 16;
    trans[2].rxlength = 16;
    trans[2].cmd = (TEMP_LOW | 0x80);
    trans[2].flags = SPI_TRANS_USE_RXDATA;
    trans[2].rx_buffer = NULL;
    trans[2].tx_buffer = NULL;
    ESP_LOGD("ACCEL_READ", "Queueing read transaction 2");
    ESP_ERROR_CHECK(spi_device_queue_trans(accel, &trans[2], portMAX_DELAY));

    ESP_LOGD("ACCEL_READ", "Receiving data from read transaction 0");
    ESP_ERROR_CHECK(spi_device_get_trans_result(accel, &receive[0],portMAX_DELAY));
    ESP_LOGD("ACCEL_READ", "Receiving data from read transaction 1");
    ESP_ERROR_CHECK(spi_device_get_trans_result(accel, &receive[1],portMAX_DELAY));
    ESP_LOGD("ACCEL_READ", "Receiving data from read transaction 2");
    ESP_ERROR_CHECK(spi_device_get_trans_result(accel, &receive[2],portMAX_DELAY));

    ESP_LOGD("ACCEL_READ", "Transferring data from read transactions");
    accel_temp_burst[0] = receive[0]->rx_data[0];
    accel_temp_burst[1] = receive[0]->rx_data[1];
    accel_temp_burst[2] = receive[0]->rx_data[2];
    accel_temp_burst[3] = receive[0]->rx_data[3];
    accel_temp_burst[4] = receive[1]->rx_data[0];
    accel_temp_burst[5] = receive[1]->rx_data[1];
    accel_temp_burst[6] = receive[2]->rx_data[0];
    accel_temp_burst[7] = receive[2]->rx_data[1];

    ESP_LOGD("ACCEL_READ", "Burst Data: %02X %02X %02X %02X %02X %02X %02X %02X",
    accel_temp_burst[0], accel_temp_burst[1], accel_temp_burst[2], accel_temp_burst[3],
    accel_temp_burst[4], accel_temp_burst[5], accel_temp_burst[6], accel_temp_burst[7]);

    ESP_LOGD("ACCEL_READ", "Transaction complete");
    return;
}

void led_w(uint8_t *led_data){
    
    ESP_ERROR_CHECK (rmt_enable( rmt_LED_north));

    ESP_LOGD("LEDW", "Setting up LED write");
    rmt_transmit_config_t led_tx = {
        .loop_count = 0  // No looping
    };

    ESP_LOGD("LEDW", "Attempting LED write");
    ESP_ERROR_CHECK(rmt_transmit(rmt_LED_north, bytes_encoder, led_data, LED_NORTH_CHAIN * 3, &led_tx));
    ESP_ERROR_CHECK(rmt_tx_wait_all_done(rmt_LED_north, portMAX_DELAY));
    ESP_LOGD("LEDW", "LED write completed");
    ESP_ERROR_CHECK (rmt_disable( rmt_LED_north));

    return;
}

void IRAM_ATTR drdy_isr_handler(void* arg) {
    is_drdy = true;

    BaseType_t xHigherPriorityTaskWoken = pdFALSE;
    vTaskNotifyGiveFromISR(drdy_task_handle, &xHigherPriorityTaskWoken);
    if (xHigherPriorityTaskWoken) {
        portYIELD_FROM_ISR();
    }
}


void IRAM_ATTR gpio_isr_handler(void* arg) {
    // Check the level of the GPIO to determine edge
    interrupt_triggered = true;
    int level = gpio_get_level(PIN_INT2);

    if (level == 1) {
        // Rising edge detected (inactivity detected)
        // Handle inactivity start here
        inactive_detect = true;
        esp_sleep_enable_ext1_wakeup(1ULL << PIN_INT2, 0);
    } 
    
    else {
        // Falling edge detected (activity resumed)
        // Handle activity resumption here
        active_detect = true;
    }

    return;
}

void handle_activity_task(void* arg) {
    while (1) {
        if (interrupt_triggered) {
            interrupt_triggered = false;  // Clear the flag

            if(inactive_detect){


                inactive_detect = false;
                
                ESP_LOGI("HANDLER", "Inactive detected");
                if (!first_inact){
                    first_inact = true;
                    ESP_LOGI("HANDLER", "Ignoring first inactivity");
                } else {
                ESP_LOGD("HANDLER", "Running inactivity sequence");
                inactivity_sequence();
                }
            }
            else if (active_detect) {
                ESP_LOGD("HANDLER", "Running activity sequence");
                activity_sequence();

            }
            
        }
        
        // Short delay to yield CPU time
        vTaskDelay(pdMS_TO_TICKS(50));
    }
}

void handle_drdy_task(void* pvParameters) {
    while (1) {
        // Wait for the ISR notification
        ulTaskNotifyTake(pdTRUE, portMAX_DELAY); // Block until notified

        ESP_LOGD("DRDY_ISR", "DRDY interrupt triggered");
    }
}

void activity_sequence() {
    active_detect = false;
    ESP_LOGI("ACTIVE", "Active detected");
    while(!inactive_detect){
        ESP_LOGD("ACTIVE", "In while loop");
        led_w(led_blue);
        vTaskDelay(pdMS_TO_TICKS(100));
    }
    return;
}

void inactivity_sequence(){
    int detected_face = -1;
    stop_timer();
    restart_timer(TIMER_DUR * 1000000);
    inactive_detect = false;
    ESP_LOGD("INACTIVE", "Inactive detected");
    led_w(led_off);
    accel_get_modes();     
    ESP_LOGE("INACTIVE", "Accelerometer values: X %.3f g, Y %.3f g, Z %.3f g",
    accel_results[0],
    accel_results[1],
    accel_results[2]);
    
    detected_face = get_face();
    while (detected_face == -1) {
        accel_get_modes();
        detected_face = get_face();
        vTaskDelay(pdMS_TO_TICKS(10));

    } 
    
    ESP_LOGE("MODES", "Face gathered: %d", detected_face + 1);

    if (detected_face == 0) roll_1();
    else if (detected_face == 19) roll_20();

    light_face(detected_face);
    vTaskDelay(pdMS_TO_TICKS(100));
    


    return;
}


void accel_get_modes() {
    float x_arr[SENSOR_DATA_GRAB_REPEATS] = {};
    float y_arr[SENSOR_DATA_GRAB_REPEATS] = {};
    float z_arr[SENSOR_DATA_GRAB_REPEATS] = {};

    int x_counter = 0, y_counter = 0, z_counter = 0;
    float x_sum = 0, y_sum = 0, z_sum = 0;

    for (int i = 0; i < SENSOR_DATA_GRAB_REPEATS; i++) {
        ESP_LOGD("MODES", "Sampling sensor");
        
        r_accel();

        // Convert raw data
        int16_t x_raw = (int16_t)((accel_temp_burst[0]) | (accel_temp_burst[1] << 8));
        int16_t y_raw = (int16_t)((accel_temp_burst[2]) | (accel_temp_burst[3] << 8));
        int16_t z_raw = (int16_t)((accel_temp_burst[4]) | (accel_temp_burst[5] << 8));

        x_arr[i] = x_raw * ACCEL_SENSITIVITY_4G;
        y_arr[i] = y_raw * ACCEL_SENSITIVITY_4G;
        z_arr[i] = z_raw * ACCEL_SENSITIVITY_4G;

        // Log raw values
        ESP_LOGD("MODES", "X_RAW: %d, Y_RAW: %d, Z_RAW: %d", x_raw, y_raw, z_raw);

        // Accumulate non-zero values
        if (fabs(x_arr[i]) > 0.01) { x_sum += x_arr[i]; x_counter++; }
        if (fabs(y_arr[i]) > 0.01) { y_sum += y_arr[i]; y_counter++; }
        if (fabs(z_arr[i]) > 0.01) { z_sum += z_arr[i]; z_counter++; }

    }

    accel_results[0] = (x_counter > 0) ? x_sum / x_counter : 0;
    accel_results[1] = (y_counter > 0) ? y_sum / y_counter : 0;
    accel_results[2] = (z_counter > 0) ? z_sum / z_counter : 0;

    ESP_LOGD("MODES", "Averages: X=%.3f g, Y=%.3f g, Z=%.3f g", accel_results[0], accel_results[1], accel_results[2]);

    
    

}

int get_face(){

    for (int i = 0; i < NUM_FACES; i++) {
        if (compare_vectors(accel_results, faces[i], TOLERANCE)) {
            ESP_LOGD("FACE MATCH", "Match found with FACE_%d\n", i + 1);
            return i; // Exit after finding the first match
        }
    }

    return -1;

}

int compare_vectors(const float a[3], const float b[3], float tolerance) {
    for (int i = 0; i < 3; i++) {
        if (fabs(a[i] - b[i]) > tolerance) {
            return 0; // Not equal
        }
    }
    return 1; // Equal
}

void light_face(int face){

    memcpy( led_current, led_off, sizeof(led_off));


    led_current[3*(led_order[face]) + 1] = 0xFF;
    led_current[3*(led_order[face]) + 2] = 0xFF;

    led_w(led_current);

    return;
}

void led_test(){

    uint8_t led_test[LED_NORTH_CHAIN * 3] = {0};

    for (int i = 0; i < LED_NORTH_CHAIN; i++){
        
        led_w(led_off);
        vTaskDelay(pdMS_TO_TICKS(2)); // Delay for 200 ms
        memcpy( led_test, led_off, sizeof(led_off));
        

        led_test[3*i] = 0x00;
        led_test[3*i+1] = 0x00;
        led_test[3*i+2] = 0x0F;

        

        led_w(led_test);
        vTaskDelay(pdMS_TO_TICKS(100)); 


    }

    led_w(led_blue);
    vTaskDelay(pdMS_TO_TICKS(1000));
    led_w(led_green);
    vTaskDelay(pdMS_TO_TICKS(1000));
    led_w(led_red);
    vTaskDelay(pdMS_TO_TICKS(1000));

    return;
}
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

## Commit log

2024-10-26 Added schematic docs and PDS
    [led20_preliminary_schematic.kicad_pcb, led20_preliminary_schematic.kicad_sch]
2024-10-28 Push current changes to Git for parallel coding
2024-10-29 Revert "Push current changes to Git for parallel coding"
    This reverts commit 042efdc79f316fea88aa70c33bcac32e68842648.
    [main.c]
2024-11-01 Big Git Commit
    Massive upload and rearrangement of most of our project files
    [Bill of Materials (Prototype).xlsx, Decision Matrix and AHP.xlsx, led20_preliminary_schematic.kicad_pcb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]
2024-11-01 Create PDS Version 1.1.pdf
    Updated L0 and L1 block diagrams, added "wireless charging capabilities" to "May" requirements
2024-11-02 Functional large burst for Accel / Gyro burst reading
    Functional, but with a ~40ms delay between bursts of 12. I will look into other ways to reduce this delay, or see if the transactions need to happen anywhere near that speed.
2024-11-03 Added KiCAD symbols
    Added KiCAD symbols for ap3602, lsm6dso32, and xiao_esp32c6.
    Place in correct library
2024-11-03 Code works for sensing interrupts
    INT1 is for SMD, INT2 is for inactivity
    [partitionTable.csv]
2024-11-03 work from today
    Added custom footprint and digikey footprints
    [charge pump footprint.kicad_pcb]
2024-11-05 Updated Schematic 11-4-24
    Removed Logic Level Shifter
    Added USB pins
    Added Test Points
    other various minor fixes
    [charge pump footprint.kicad_pcb, led20_updated_schematic_11_4_24.kicad_sch]
2024-11-05 Final revision of Updated Schematic 11-4-24
    [led20_updated_schematic_11_4_24.kicad_sch]
2024-11-05 PCB In Progress
    Progress for the PCB layout. Tracing and microcontroller footprint still needs to be done.
    [led20_updated_schematic_11_4_24.kicad_pcb]
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2024-11-05 Updated PCB
    Added esp32 footprint
    [led20_updated_schematic_11_4_24.kicad_pcb]
2024-11-05 minor fixes
    [led20_updated_schematic_11_4_24.kicad_sch]
2024-11-06 Updated PCB
    Pins for Microcontroller on schematic had to be changed to reflect the footprint pin out. This may need closer attention for all ICs, i'll double check that tomorrow. Also found connector for battery. Changed battery symbol in schematic to avoid errors. LED array was combined to make one 20 LED array instead of two seperate 10 LED arrays. Points for wireless charging still need to be added to both schematic and PCB
    [led20_updated_schematic_11_4_24.kicad_pcb, led20_updated_schematic_11_4_24.kicad_sch]
2024-11-06 Updated PCB and Schematic
    Changed schematic to include charging contact points and double checked pinouts on ICs
    [led20_updated_schematic_11_4_24.kicad_pcb, led20_updated_schematic_11_4_24.kicad_sch]
2024-11-07 Updated PCB and Schematic
    [led20_updated_schematic_11_4_24.kicad_pcb, led20_updated_schematic_11_4_24.kicad_sch]
2024-11-07 Able to control every aspect of the project so far, and added breadboard prototype information
2024-11-07 dont worry bout it sweetheart
    [led20_preliminary_layout_11_6_24.kicad_pcb, led20_updated_schematic_11_6_24.kicad_sch]
2024-11-11 refined accel and gyro outputs for easier computation.
    I was bored and not very tired, but now my brain hurts :D
2024-11-12 Filtering set up, inactivity set up to trigger interrupt signal after ~10 seconds
2024-11-12 Create Bill of Materials (Version 1.0).xlsx
    [Bill of Materials (Version 1.0).xlsx]
2024-11-12 Update Bill of Materials (Version 1.0).xlsx
    [Bill of Materials (Version 1.0).xlsx]
2024-11-12 PCB and Schematic Update
    [led20_updated_schematic_11_4_24.kicad_pcb, led20_updated_schematic_11_4_24.kicad_sch]
2024-11-12 Added Functional Decomposition
    [led20_preliminary_layout_11_6_24.kicad_pcb]
2024-11-12 PCB and Schematic Update
    Updated PCB with traces and ground planes. Needs review. Battery symbol for schematic was removed - JST connector remains in its place.
    [led20_updated_schematic_11_4_24.kicad_pcb, led20_updated_schematic_11_4_24.kicad_sch]
2024-11-12 Resubmit
    see previous notes
    [led20_preliminary_layout_11_6_24.kicad_pcb]
2024-11-12 Update to PCB
    Moved caps closer to ICs
    [led20_updated_schematic_11_4_24.kicad_pcb, led20_updated_schematic_11_4_24.kicad_sch]
2024-11-13 Create Bill of Materials Version 2.xlsx
    [Bill of Materials Version 2.xlsx]
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2024-11-14 Working interrupt detection and handling, switches between red and green when interrupts are detected while also outputting data
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2024-11-16 Handful of Schemi/PCB directory edits
    [Bill of Materials v1.xlsx, Bill of Materials v2.xlsx, charge pump footprint.kicad_pcb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]
2024-11-16 Updated Directory and added new project contet
    [LED20.kicad_pcb, LED20.kicad_sch, led20_preliminary_layout_11_6_24.kicad_pcb]
2024-11-16 More CAD directory changes
    [LED20.kicad_pcb, LED20.kicad_sch, charge pump footprint.kicad_pcb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]
2024-11-16 Update PCB
    Updated test points, vias, and pcb traces. Added version number and team name to back of PCB.
    [LED20.kicad_pcb, LED20.kicad_sch]
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2024-11-20 PCB v5.2 local version WIP
    Moved connectors, accel/gyro, charge pump, retraced, etc.
    Added date to silkscreen
    Still needs ground stitching
    DRC yields handful of errors/warnings, needs review
    [LED20.kicad_pcb, LED20.kicad_sch]
2024-11-20 PCB and Schematic Update
    Updated PCB and Schematic with diode, transistor and resistor for piezo speaker driving circuit
    [LED20.kicad_pcb, LED20.kicad_sch]
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2024-11-20 Updated PCB
    added 2.1mm mounting hole. Seems quite large may have clearance issues.
    [LED20.kicad_pcb]
2024-11-21 Updated PCB
    Made new folder as well called v5.4 local, just in case we need v5.3
    [LED20.kicad_pcb, LED20.kicad_sch]
2024-11-21 Create LED20 no Cuts v2.f3d
    [LED20 no Cuts v2.f3d]
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2024-11-21 We did it
    [LED20-B_Cu.gbr, LED20-B_Fab.gbr, LED20-B_Mask.gbr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]
2024-11-21 Eliminated redundant backups
    [LED20-B_Cu.gbr, LED20-B_Fab.gbr, LED20-B_Mask.gbr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]
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2024-12-05 Add buzzer and LED test functions
    [main.c]
2024-12-05 Updated schematic and pcb layout to reflect charge pump !shdn connection change and fix esp32 footprint shenanigans
    LED v5.6
    [LED20-B_Cu.gbr, LED20-B_Fab.gbr, LED20-B_Mask.gbr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]
2024-12-05 Small revisions to final schematic, made pdf
    [LED20.kicad_sch]
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2024-12-07 Create Bill of Materials v4.xlsx
    [Bill of Materials v4.xlsx]
2024-12-07 Deleted "Documentation" directory - unneeded
    [LED20.kicad_pcb]
2024-12-11 Rename Charger Testing (Maybe Final Version) v5.f3d to Charger Testing Final Version v5.f3d
    [Charger Testing Final Version v5.f3d]
2024-12-11 Rename LED20 Fat Ass Pegs (Updated) v3.f3d to LED20 Testing Pegs v3.f3d
    [LED20 Testing Pegs v3.f3d]
2024-12-11 Updated BOM
    [Bill of Materials v5.xlsx]
